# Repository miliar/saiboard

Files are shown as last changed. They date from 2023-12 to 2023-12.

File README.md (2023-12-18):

# Saiboard
Saiboard is an open-source Go board that combines tradition with technology.

Experience the thrill of Go on a real board, enhanced by AI guidance and analysis tools.

Play against AI, review your games with AI assistance, and elevate your Go skills to new heights.

https://github.com/miliar/saiboard/assets/35922697/eb32aec5-f142-464d-a071-56e9dbfe0f72

Features:

- Wooden Go [board](https://github.com/miliar/saiboard/tree/main/board) for authentic gameplay
- Sensory [electronics](https://github.com/miliar/saiboard/tree/main/electronics) for accurate move detection and LED feedback
- Heavy, magnetic Go [stones](https://github.com/miliar/saiboard/tree/main/stones) for a stable and engaging experience
- [Software](https://github.com/miliar/saiboard/tree/main/software ) with integrated AI system KataGo for expert insights and game recommendations
- User-friendly [web app](https://github.com/miliar/saiboard/tree/main/software/flutter/saiboard) for effortless control and interaction

## App
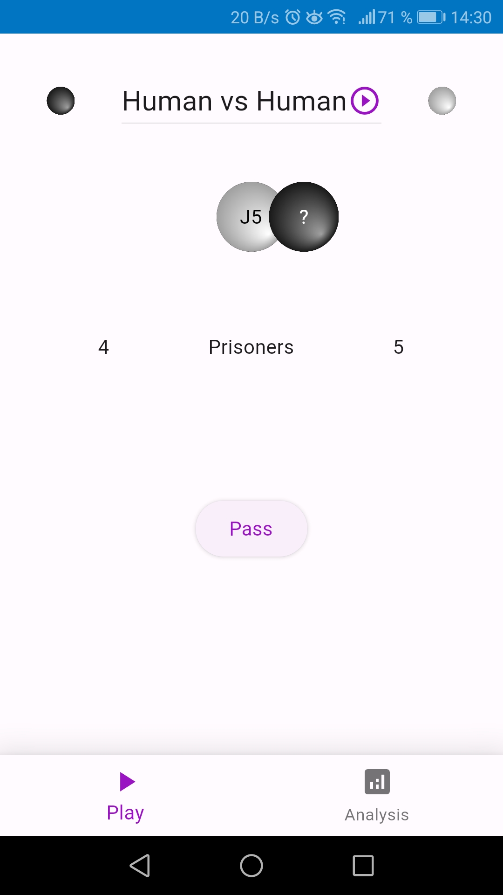
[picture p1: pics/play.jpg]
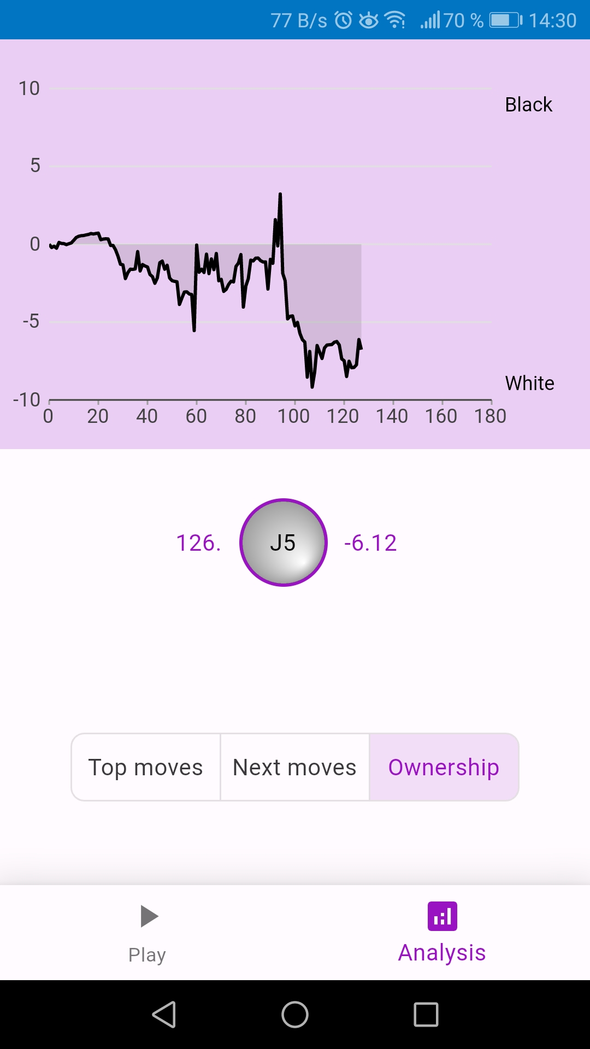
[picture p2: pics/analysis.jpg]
  

## Board
### Next moves
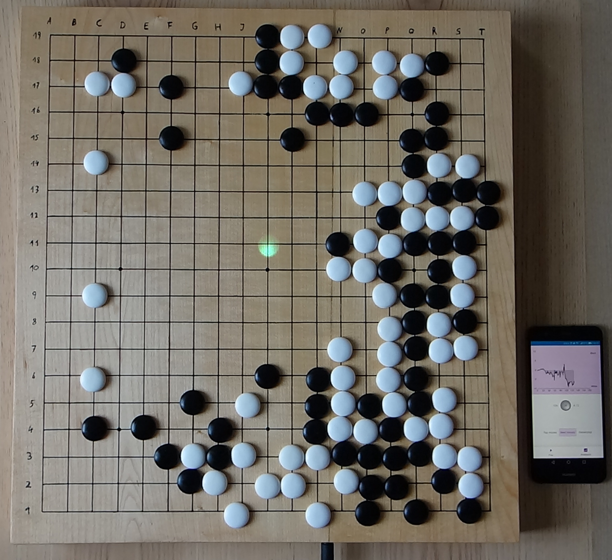
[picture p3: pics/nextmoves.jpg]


### Top moves
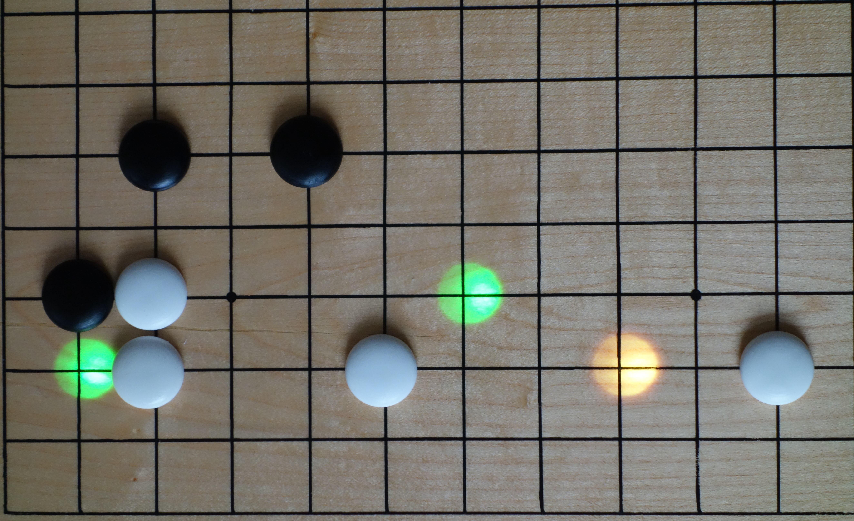
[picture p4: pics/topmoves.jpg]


### Ownership
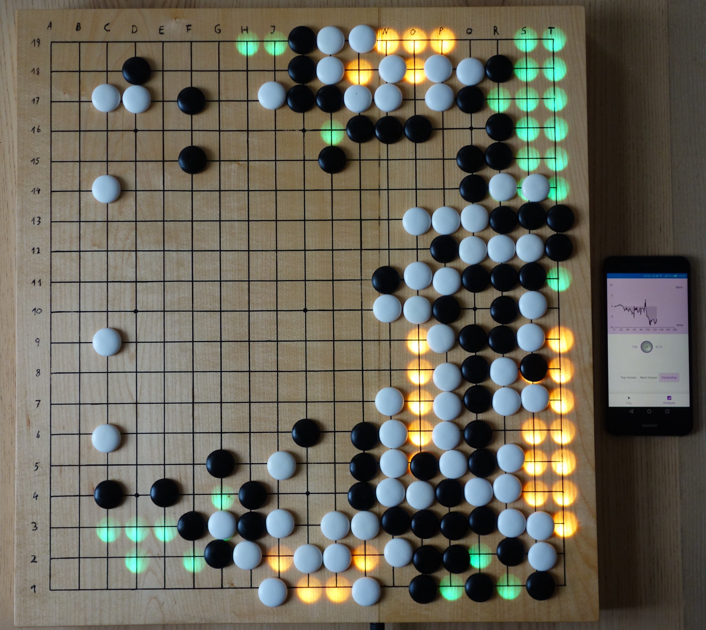
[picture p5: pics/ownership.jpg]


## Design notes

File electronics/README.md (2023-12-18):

# Electronics
The electronics consists of one touch plate, an array of 19x19 hall sensors (for detecting magnets) and LEDs. \
The touch plate is used to detect when a move is finished, so that sliding the stone in position is possible. \
It is controlled by an ESP32S3 microcontroller.\
To make the manufacturing process easier, the board is divided into several smaller PCBs. \
There is a power connection for a raspberry pi.

## How to build
### PCBs

- [Order](https://jlcpcb.com/) PCB/ Stencil
- [Solderpaste](https://www.mouser.de/ProductDetail/Chip-Quik/TS391AX50?qs=1mbolxNpo8c66lK8U%252Bbg8g%3D%3D)
- Solder led side first
- [Reflow oven](https://www.ninjakitchen.de/produkte/ninja-foodi-8-in-1-multifunktionsofen-sp101eu-zidSP101EU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): Bake 3 min, 0-90s: 125° C, 90-180s: 230° C, then open door
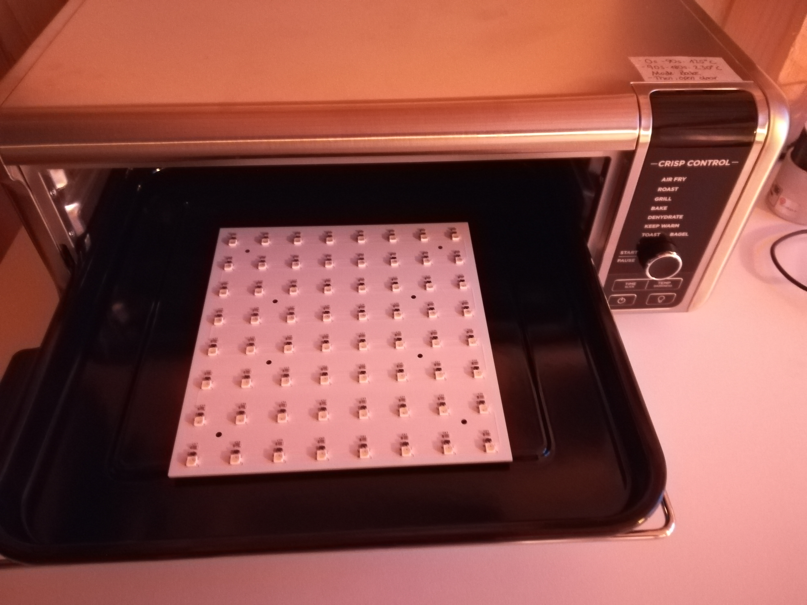
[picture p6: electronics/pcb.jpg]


- Print [plastic parts](/electronics/3d_prints/)
- Place pcb mask on first side, apply paste to the second side. Then remove pcb mask and bake pcb while placed on e.g. nuts

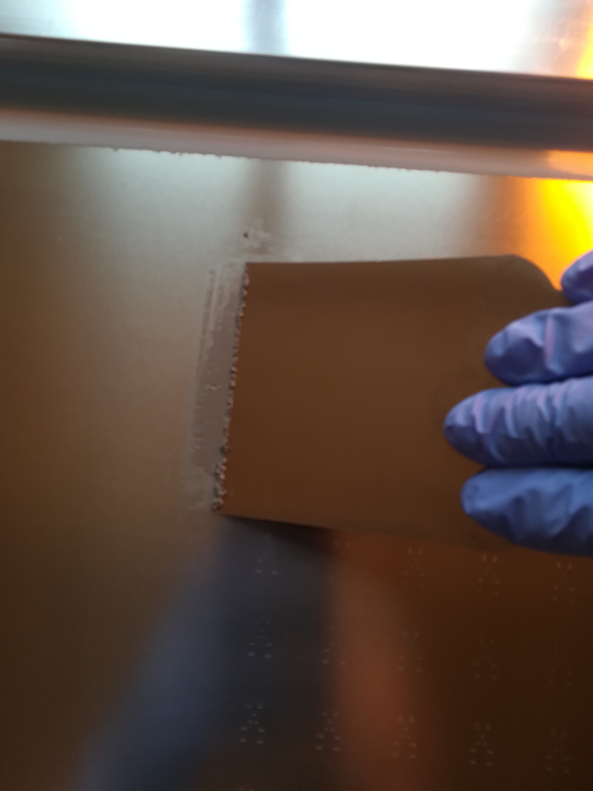
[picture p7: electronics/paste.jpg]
  

### Touch plate
Put copper foil on printed pcb-masks, remove foil from holes. Eletrical and physical connect all pcb masks. Glue non copper side to pcb first side with double sided tape. Solder connection to copper side and connect to touch pin of microcontroller.

### Mounting
- Press [esp32s3](https://docs.espressif.com/projects/esp-idf/en/latest/esp32s3/hw-reference/esp32s3/user-guide-devkitc-1.html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) in socket
- Use [screws](https://www.amazon.de/gp/product/B00XPJG1OC/ref=ppx_yo_dt_b_asin_title_o05_s00?ie=UTF8&psc=1) out of **stainless steel**.
- Enlarge mount holes of raspberry pi 4 to 3mm and fix it with the plastic mount. Connect power pins to board.
- Connect board power out to [adapter](https://www.amazon.de/Delock-Terminalblock-2pin-5mm-65421/dp/B009PH1J5Y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). Glue adapter into hole on the side of the board.
- Use a 5V/ 10A, 50W [power supply](https://www.amazon.de/LEICKE-Netzteil-Adapter-WS2812B-LED8806/dp/B07YVBHH6K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)

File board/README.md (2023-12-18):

# Board
The board has a top made of plywood with holes for the LED lights. \
A layer of veener is put over the holes to make a smooth surface. \
Resin is poured into the holes to protect the lights and make the board more sturdy.

## How to build
- Cut [pieces](/board/cnc_files/) out of plywood.
  - Thickness Sides: 10 mm Bottom: 5 mm Top: 6,5 mm
- [Glue](https://www.amazon.de/Titebond-Classic-Holzleim-118-506/dp/B0044UKJ62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) and clamp over night
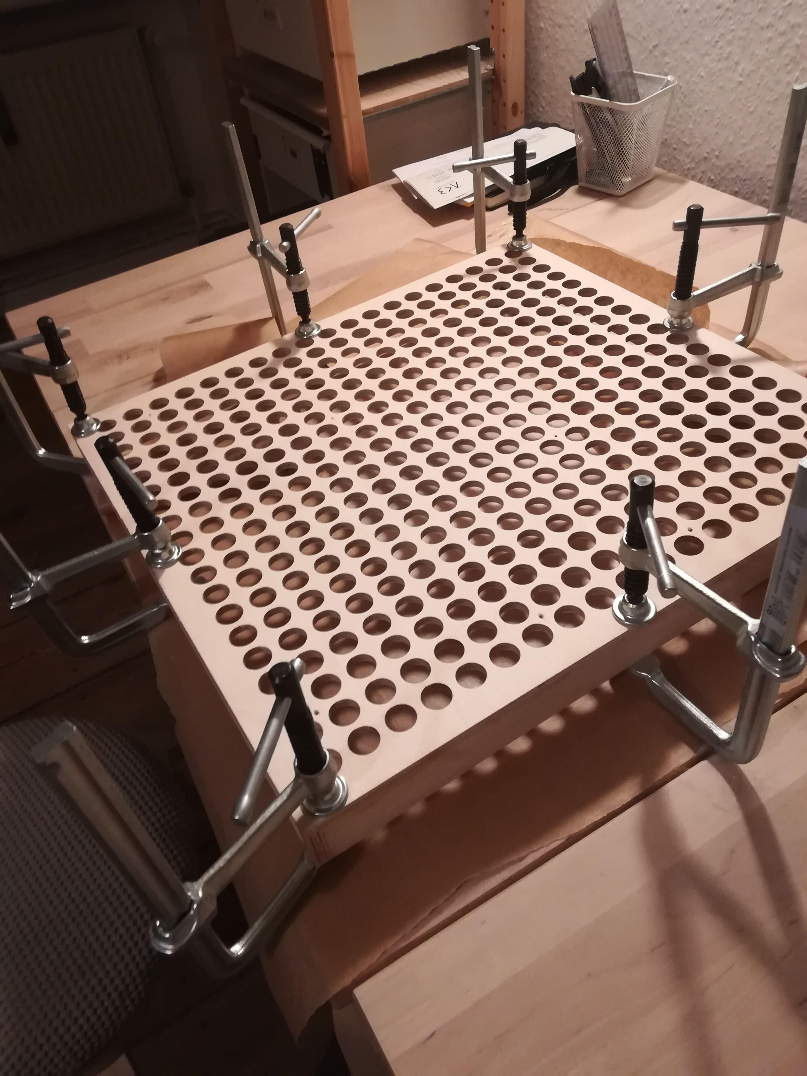
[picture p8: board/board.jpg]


- Sanding
- Cut pieces out of 0,6 mm thick veener, a bit larger area than top piece of board
- Put glue to the top of the board and to the veener, let it dry, then iron on veener.
- Cut or sand veener to size
- (Oil finish)
- Fill inside with enough resin to cover holes
- 4 layers of [poly](https://www.amazon.de/Minwax-polycryl-40910-wipe-%C3%96l-basierende-1-pint/dp/B01MU1VFWV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)
- Apply the grid. This [pen](https://www.amazon.de/rOtring-isograph-Tuschef%C3%BCller-0-8/dp/B000USK8KY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) works great. You can assemble the two 3d print files with a spring for a penholder similiar to [this instruction](https://www.instructables.com/Spring-loaded-CNC-Penholder-for-Rapidograph-techni/) and [use the cnc to apply the lines](https://www.reddit.com/r/baduk/comments/13xi005/tachi_mori_2023/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). Apply star points by hand.
- Finish with some layers of poly and sanding

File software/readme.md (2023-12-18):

# Software
The microcontroller chip on the board creates a local Wi-Fi network, to which you will need to connect your device. Once connected, you can access the Saiboard web interface by going to the local address 192.168.4.5:8000 .

The backend and frontend of Saiboard are hosted on the local Raspberry Pi. This setup keeps everything bundled into the board.

If you want to use a more powerful machine for a stronger and faster AI, you can install the backend on a different device.

## Architecture

The core of Saiboard's architecture is built around three main components:

- [esp32s3](https://github.com/miliar/saiboard/tree/main/software/esp32s3): This microcontroller chip handles the board's physical controls, communicates with the backend server, and creates the local Wi-Fi network.

- [backend](https://github.com/miliar/saiboard/tree/main/software/backend): This server software runs on the Raspberry Pi and provides the AI functionality, game logic, and interface capabilities.

- [saiboard](https://github.com/miliar/saiboard/tree/main/software/flutter/saiboard): This is the user interface (UI) part of Saiboard, which runs in your web browser and displays the game information and AI insights and also allows you to control the board directly.

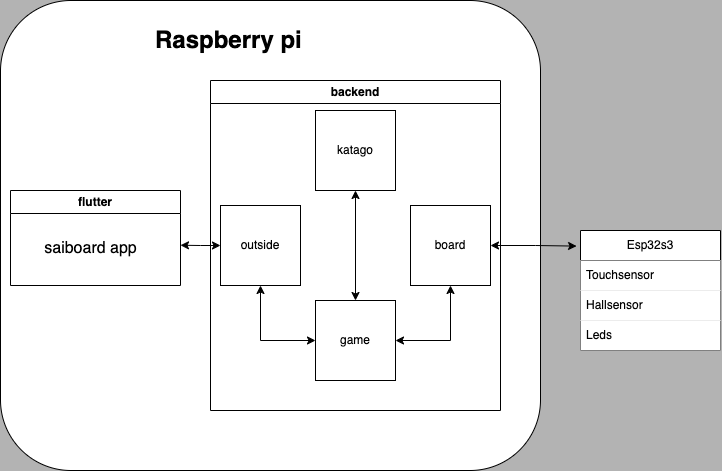
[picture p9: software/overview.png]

## Set up rasberry pi 4
- Install raspos 64 bit lite with ssh https://www.tomshardware.com/reviews/raspberry-pi-headless-setup-how-to,6028.html
- Install docker https://docs.docker.com/engine/install/debian/
- Add network in /etc/wpa_supplicant/wpa_supplicant.conf
- Prepend domain-name-servers 8.8.8.8, 8.8.4.4; >> /etc/dhcp/dhclient.conf , then sudo dhclient
- Set static ip for rasberry pi to 192.168.4.5(flutter needs static real ip for websocket) https://www.tomshardware.com/how-to/static-ip-raspberry-pi
- Add start up to /etc/rc.local:
```
    # docker backend
    sudo docker compose -f /home/rashid/backend/docker-compose.yml  up -d
    # flutter
    (cd /home/rashid/flutter  && sudo python -m http.server 8000) &
```

## Deploy to rasberry pi 4
### Deploy flutter
- `cd software/flutter/saiboard`
- `flutter clean`
- `flutter build web --web-renderer canvaskit --release`  https://docs.flutter.dev/deployment/web
- change wifi to saiboard
- `scp -r build/web/* rashid@saiboardrasp.local:/home/rashid/flutter` https://www.simplified.guide/ssh/copy-file
- delete browser cache for app

### Deploy backend
- `scp -r ../../backend/* rashid@saiboardrasp.local:/home/rashid/backend`
- `ssh saiboardrasp.local`
- `rm backend/katago/Dockerfile & mv backend/katago/Dockerfile_rasp backend/katago/Dockerfile`
- change network on rasberry pi to internet (`sudo nano /etc/wpa_supplicant/wpa_supplicant.conf`)
- reboot, connect via wifi internet,`ssh saiboardrasp.local` 
- `cd backend`
- `docker compose down`
- `docker compose build`
- In case of build errors like "Could not connect to ports.ubuntu.com:80", try:
    - `sudo dhclient`
    - `docker image prune -a`
- `docker compose up`
- change network back to saibord, reboot rasberry pi

## Deploy to esp32s3
- [linux/macos](https://docs.espressif.com/projects/esp-idf/en/latest/esp32s3/get-started/linux-macos-setup.html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)
- [via vscode extension](https://github.com/espressif/vscode-esp-idf-extension/blob/HEAD/docs/tutorial/basic_use.md)

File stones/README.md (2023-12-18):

# Stones
The stones are made from resin. \
They are filled with a small magnet that is enclosed in a hexagonal nut. This design serves two purposes: it helps to shield the magnetic field from interfering with others, and it adds weight to the stone for a better gaming experience. \
Each stone weighs approximately 3 grams. 

## How to make the silicone mold
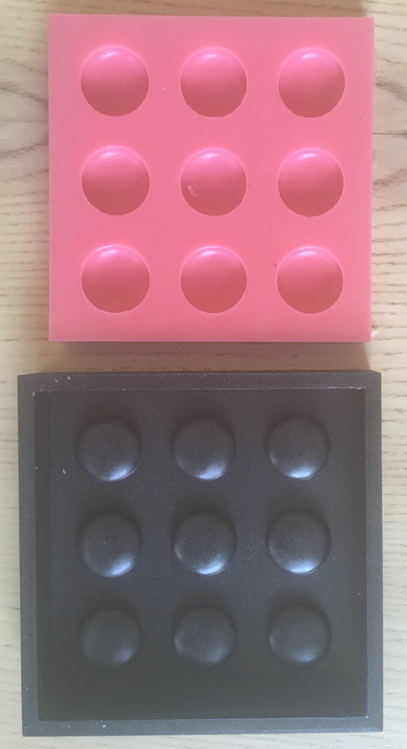
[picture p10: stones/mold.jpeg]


- 3d print the positive mold
- Sand it
- Use [Primer/Filler](https://www.amazon.de/edding-Permanent-Spray-Kunststoffgrundierung-Kunststoff-Oberfl%C3%A4chen/dp/B00CSLMC0U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) for smooth surface
- Fill with 130 g [silicone](https://www.amazon.de/Wagnersil-Premium-Silikon-Kautschuk-Dubliersilikon/dp/B01703HDWW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)

## How to make stones
- Mix [resin](https://www.amazon.de/Epoxidharz-Qualit%C3%A4t-geruchsarm-Laminier-Schutzhandschuhe/dp/B07D3SB9M9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) with 5% [color](https://www.amazon.de/100g-Farbpaste-schwarz-RAL-9005/dp/B00BIZDTEA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)
- Fill silicone mold with 0,3 ml
- Let it cure
- Push or hammer in 7x4 mm N35 neodym magnets in hexagon nut **zinc plated**( important because of magnetic properties) steel DIN 439 BM 8x1
- Place magnets into mold, **opposite** magnet direction for **each color**
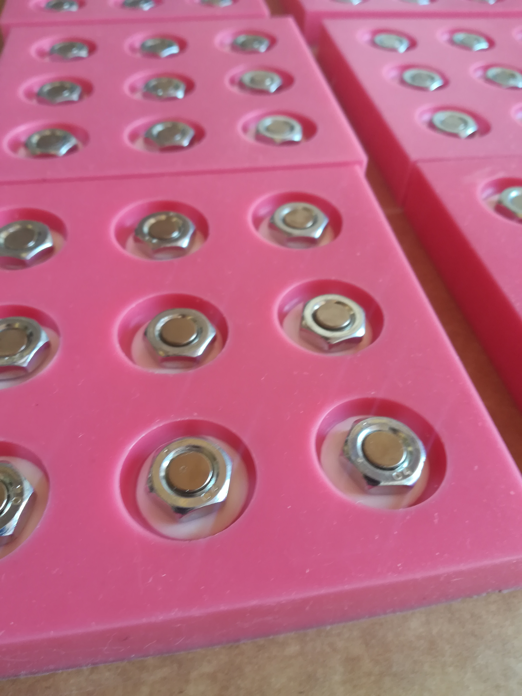
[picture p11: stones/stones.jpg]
  
- Fill up with 1,3 ml resin
- Remove bubbles with torch
- After curing, remove sharp edges by wet sanding of flat bottom and edge. For this, 3d print the stone holder and add one of the magnets to the hole.
- Rinse black stones with isopropanol and polish with a bit oil

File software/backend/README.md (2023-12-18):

# Overview
Backend runs 4 containers.
- [board](https://github.com/miliar/saiboard/tree/main/software/backend/board) interfaces with the physical board.
   

- [katago](https://github.com/miliar/saiboard/tree/main/software/backend/katago) is running the [katago analysis engine](https://github.com/lightvector/KataGo/blob/master/docs/Analysis_Engine.md) inside a docker container. There a 2 Dockerfiles for different host machine architectures
  

- [game](https://github.com/miliar/saiboard/tree/main/software/backend/game) contains all game logic.
   

- [outside](https://github.com/miliar/saiboard/tree/main/software/backend/board) interfaces with the UI.

It is deployed to a raspberry pi, but could also run from a more powerful server.
### Katago benchmark on raspberry pi 4
benchmark_rp4

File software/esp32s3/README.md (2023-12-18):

# Overview
The code creates a WiFi network with the name "saiboard" and the password "saiboard". \
It then runs a server that accepts TCP connections. \
The server responds to requests to turn the LED on or off, and it also sends sensor data back to the client. \
For more details, please see the accompanying [notebook](https://github.com/miliar/saiboard/blob/main/software/esp32s3/test_basic_components.ipynb).

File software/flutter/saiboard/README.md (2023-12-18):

# Overview
This Flutter web app is hosted on a Raspberry Pi and allows you to play against AI or a human opponent locally.

benchmark_rp4  benchmark_rp4

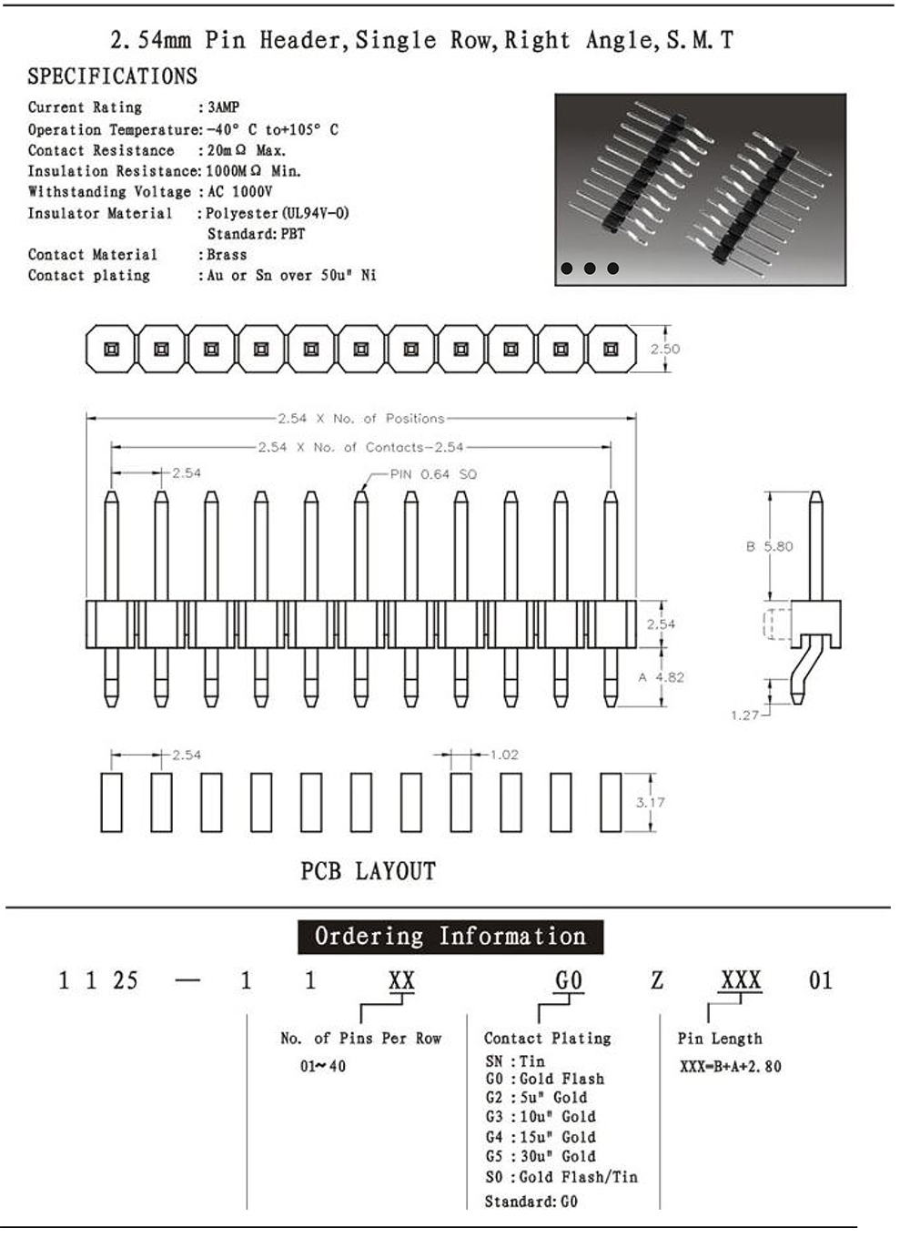
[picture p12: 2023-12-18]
electronics/datasheets/BOARD_CONNECTOR_MALE.jpg

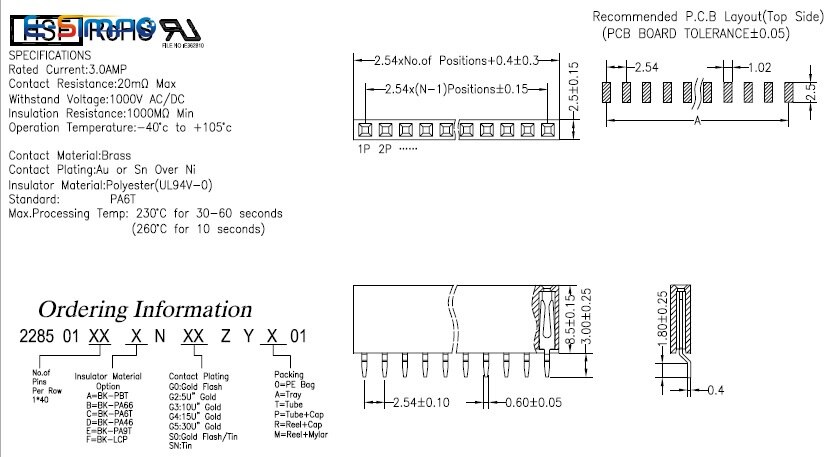
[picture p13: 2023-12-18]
electronics/datasheets/BOARD_CONNECTOR_FEMALE.jpg

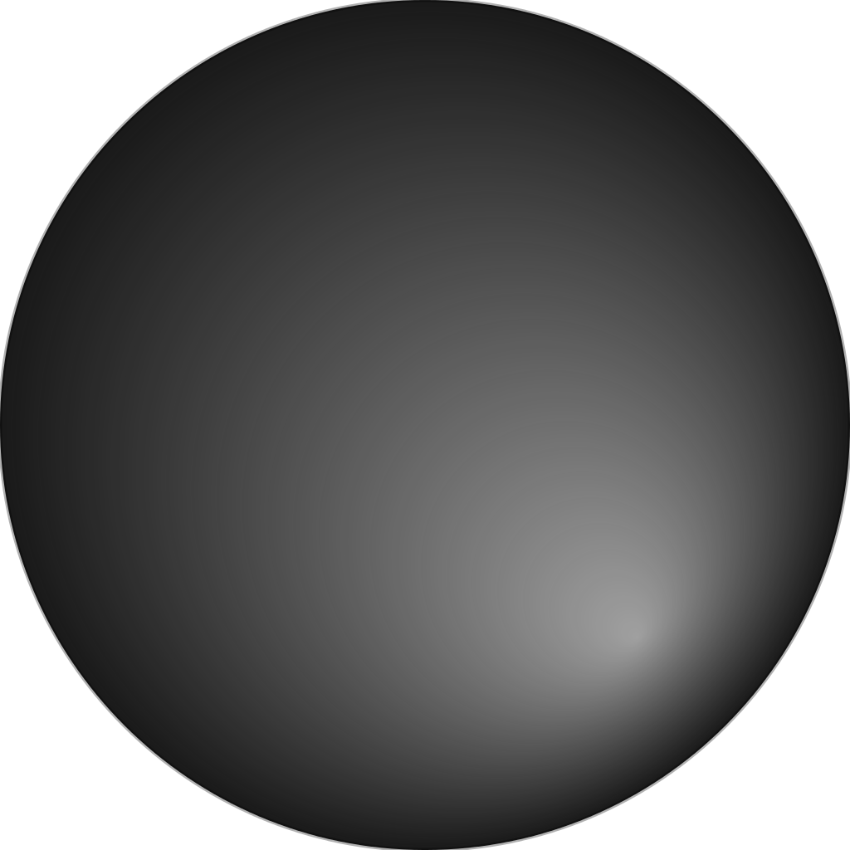
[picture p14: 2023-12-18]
software/flutter/saiboard/assets/images/black.png

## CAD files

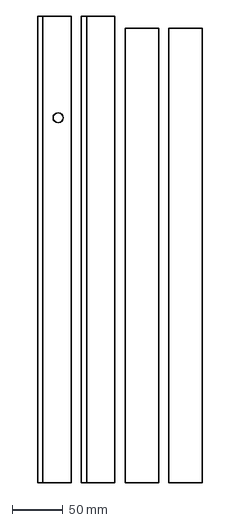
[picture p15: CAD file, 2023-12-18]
board/cnc_files/side.dxf
162.0 x 460.0 mm

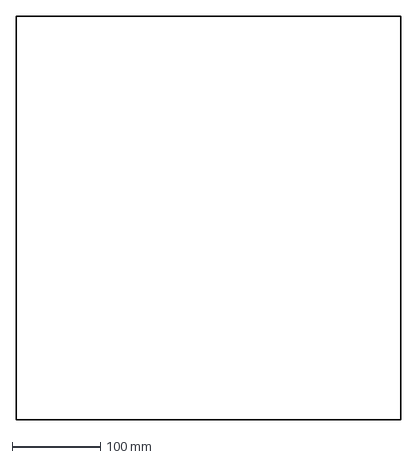
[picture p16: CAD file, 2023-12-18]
board/cnc_files/bottom.dxf
436.0 x 458.0 mm

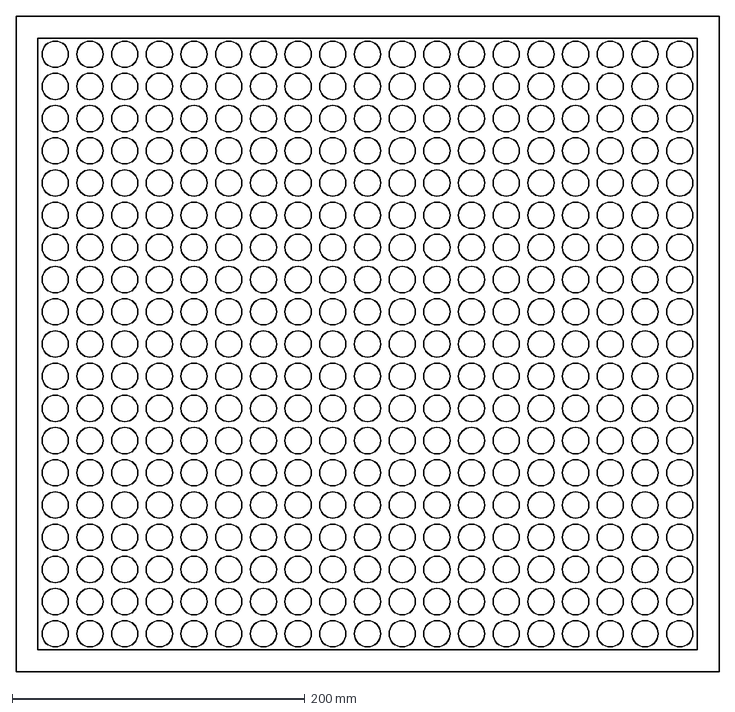
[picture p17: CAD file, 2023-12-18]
board/cnc_files/top.dxf
480.3 x 448.0 mm

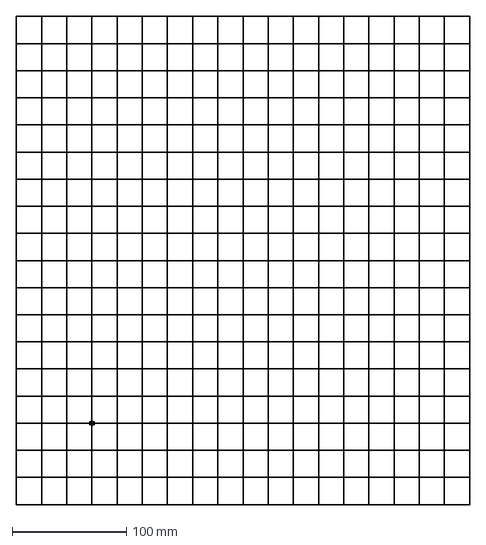
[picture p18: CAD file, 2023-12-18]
board/cnc_files/grid.dxf
396.0 x 426.6 mm

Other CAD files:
board/3d_prints/pen_part1.f3d
board/3d_prints/pen_part2.f3d
board/cnc_files/Top.f3d
board/cnc_files/bottom.f3d
board/cnc_files/grid.f3d
board/cnc_files/side.f3d
electronics/3d_prints/11x3_pcb_mask.f3d
electronics/3d_prints/3x8_pcb_mask.f3d
electronics/3d_prints/8x3_pcb_mask.f3d
electronics/3d_prints/raspberry_pi_mount.f3d
stones/3d_prints/go_stones_mold.f3d
stones/3d_prints/stone_holder.f3d

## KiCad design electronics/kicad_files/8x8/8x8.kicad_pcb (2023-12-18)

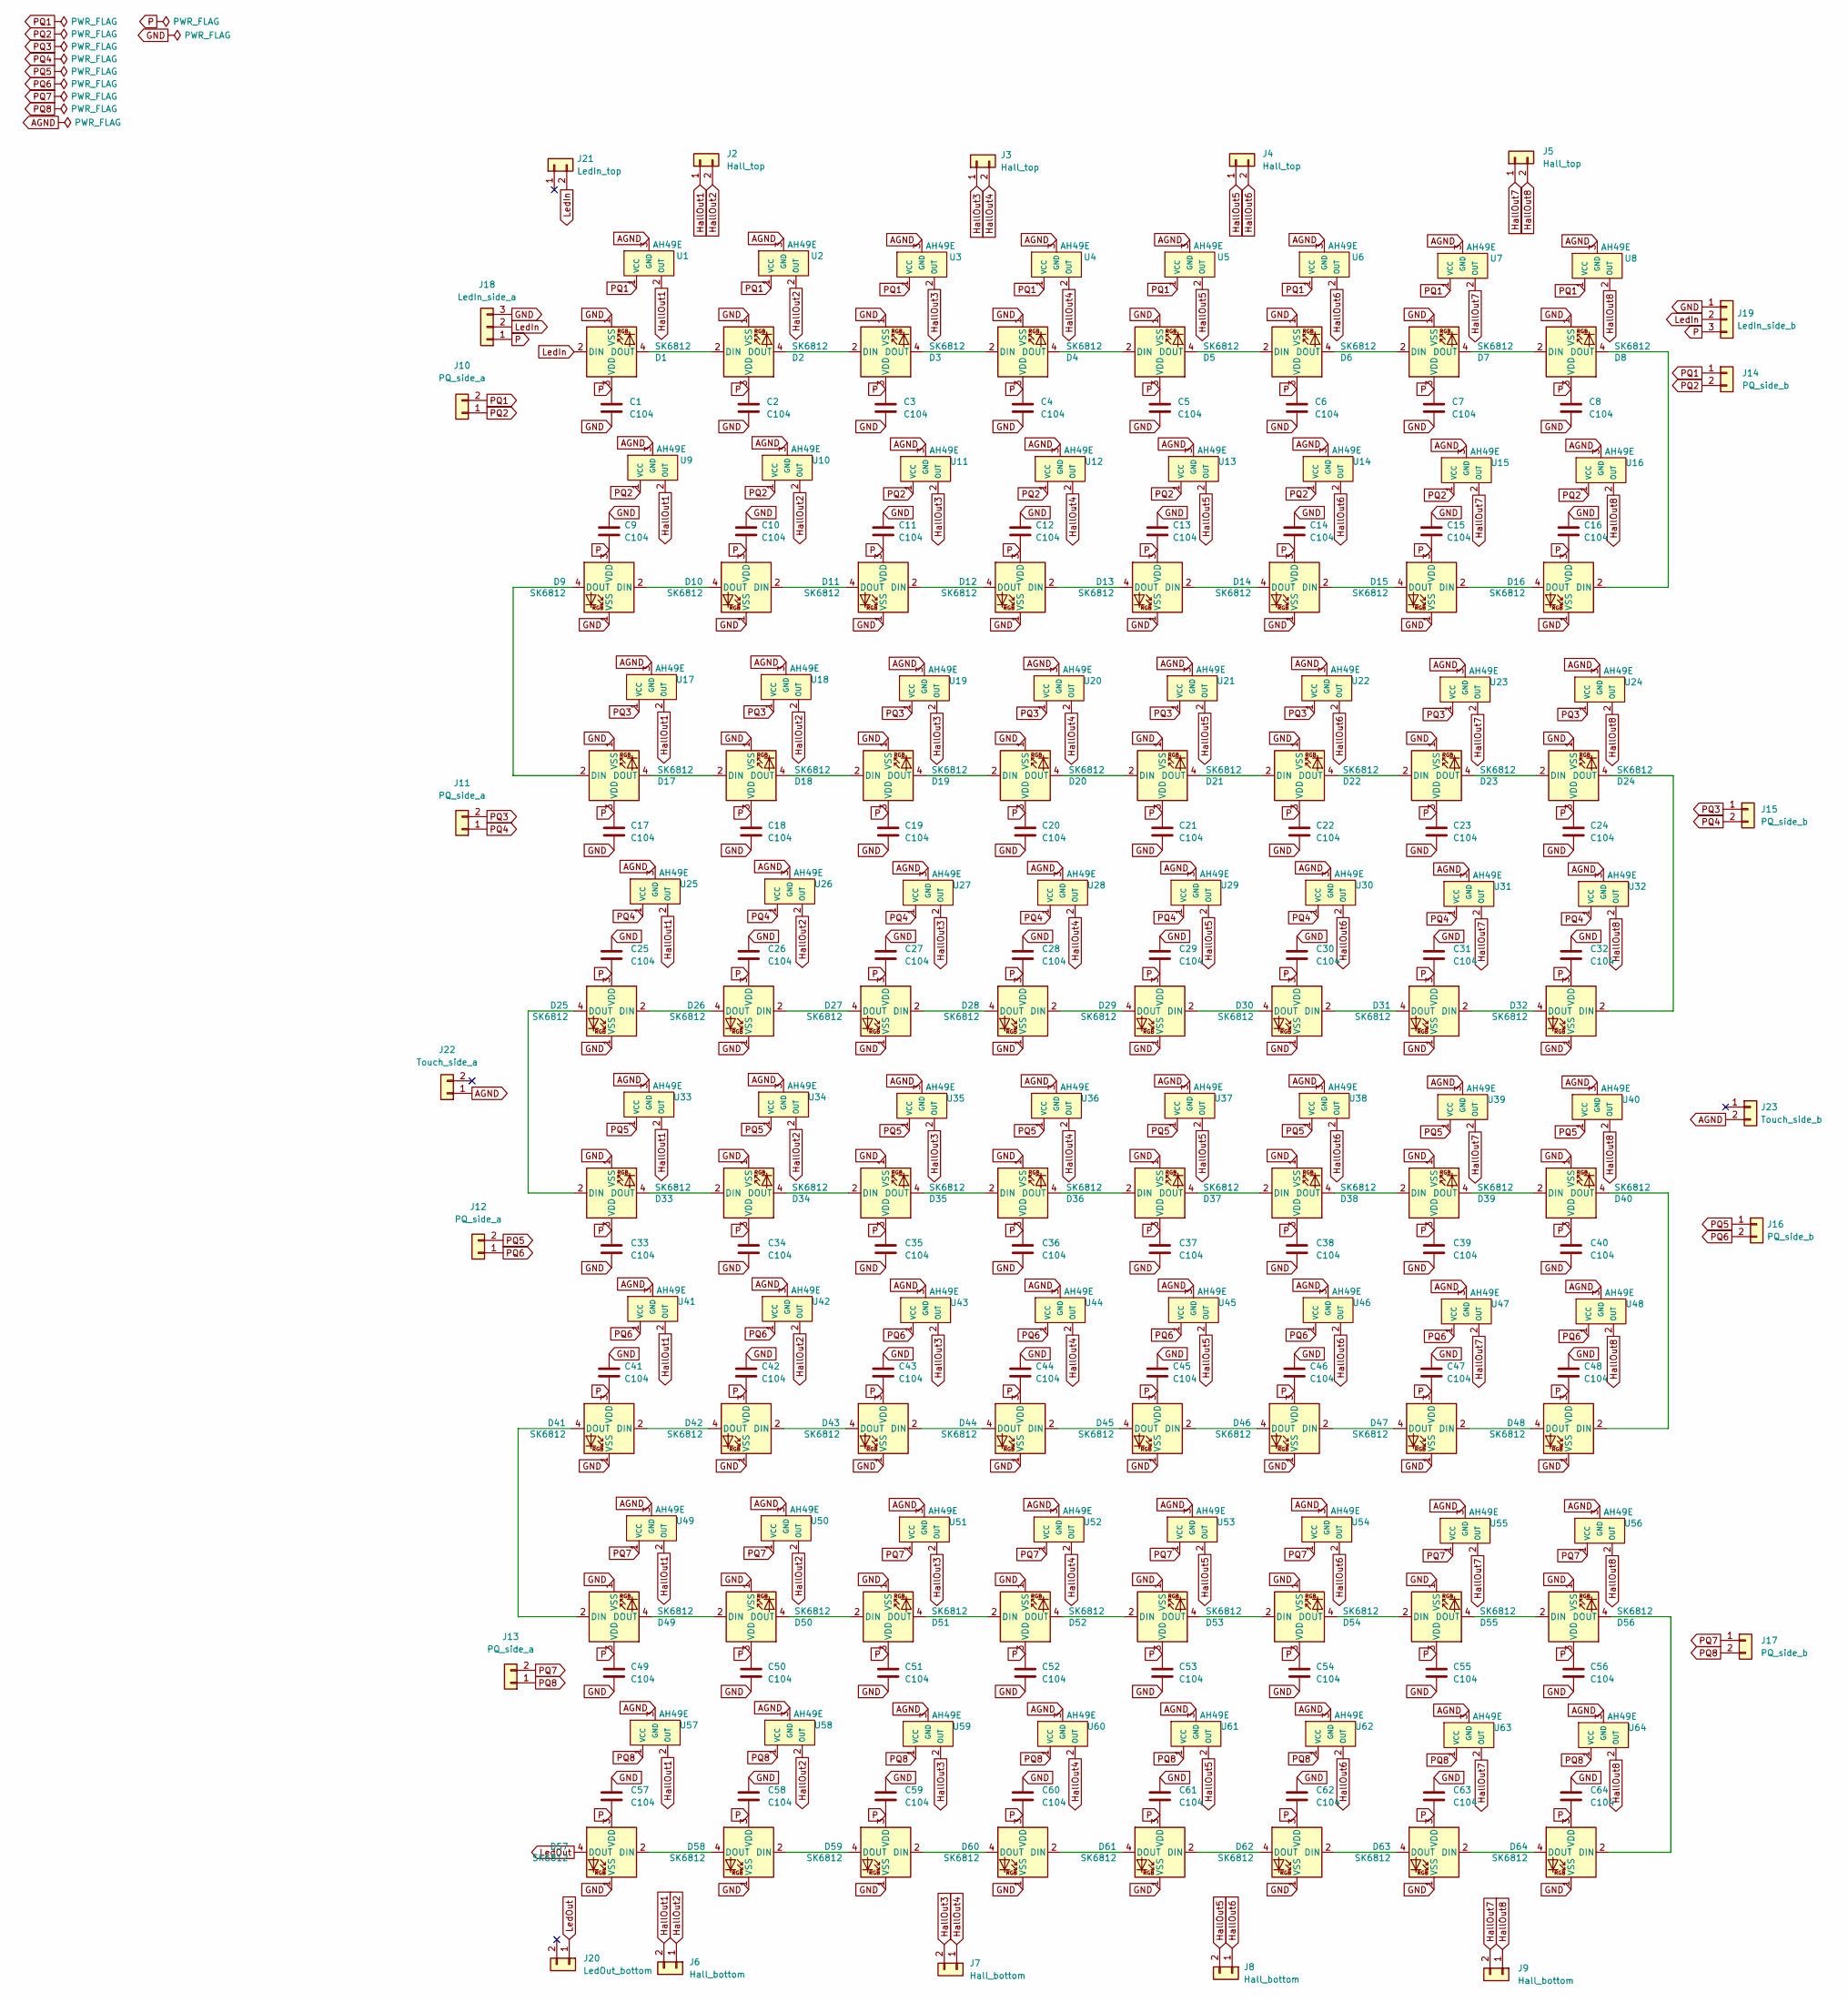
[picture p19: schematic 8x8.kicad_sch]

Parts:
C1, C2, C3, C4, C5, C6, C7, C8, C9, C10, C11, C12, C13, C14, C15, C16, C17, C18, C19, C20, C21, C22, C23, C24, C25, C26, C27, C28, C29, C30, C31, C32, C33, C34, C35, C36, C37, C38, C39, C40, C41, C42, C43, C44, C45, C46, C47, C48, C49, C50, C51, C52, C53, C54, C55, C56, C57, C58, C59, C60, C61, C62, C63, C64: C104; C_1206_3216Metric
D1, D2, D3, D4, D5, D6, D7, D8, D9, D10, D11, D12, D13, D14, D15, D16, D17, D18, D19, D20, D21, D22, D23, D24, D25, D26, D27, D28, D29, D30, D31, D32, D33, D34, D35, D36, D37, D38, D39, D40, D41, D42, D43, D44, D45, D46, D47, D48, D49, D50, D51, D52, D53, D54, D55, D56, D57, D58, D59, D60, D61, D62, D63, D64: SK6812; LED_SK6812_PLCC4_5.0x5.0mm_P3.2mm
J2, J3, J4, J5: Hall_top; PinHeader_1x02_P2.54mm_Horizontal_SMD
J6, J7, J8, J9: Hall_bottom; PinSocket_1x02_P2.54mm_Horizontal_SMD
J10, J11, J12, J13: PQ_side_a; PinSocket_1x02_P2.54mm_Horizontal_SMD
J14, J15, J16, J17: PQ_side_b; PinSocket_1x02_P2.54mm_Horizontal_SMD
J18: LedIn_side_a; PinSocket_1x03_P2.54mm_Horizontal_SMD
J19: LedIn_side_b; PinSocket_1x03_P2.54mm_Horizontal_SMD
J20: LedOut_bottom; PinSocket_1x02_P2.54mm_Horizontal_SMD
J21: LedIn_top; PinHeader_1x02_P2.54mm_Horizontal_SMD
J22: Touch_side_a; PinSocket_1x02_P2.54mm_Horizontal_SMD
J23: Touch_side_b; PinSocket_1x02_P2.54mm_Horizontal_SMD
U1, U2, U3, U4, U5, U6, U7, U8, U9, U10, U11, U12, U13, U14, U15, U16, U17, U18, U19, U20, U21, U22, U23, U24, U25, U26, U27, U28, U29, U30, U31, U32, U33, U34, U35, U36, U37, U38, U39, U40, U41, U42, U43, U44, U45, U46, U47, U48, U49, U50, U51, U52, U53, U54, U55, U56, U57, U58, U59, U60, U61, U62, U63, U64: AH49E; SOT-23

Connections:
AGND: J22.1, J23.2, U1.3 (GND), U2.3 (GND), U3.3 (GND), U4.3 (GND), U5.3 (GND), U6.3 (GND), U7.3 (GND), U8.3 (GND), U9.3 (GND), U10.3 (GND), U11.3 (GND), U12.3 (GND), U13.3 (GND), U14.3 (GND), U15.3 (GND), U16.3 (GND), U17.3 (GND), U18.3 (GND), U19.3 (GND), U20.3 (GND), U21.3 (GND), U22.3 (GND), U23.3 (GND), U24.3 (GND), U25.3 (GND), U26.3 (GND), U27.3 (GND), U28.3 (GND), U29.3 (GND), U30.3 (GND), U31.3 (GND), U32.3 (GND), U33.3 (GND), U34.3 (GND), U35.3 (GND), U36.3 (GND), U37.3 (GND), U38.3 (GND), U39.3 (GND), U40.3 (GND), U41.3 (GND), U42.3 (GND), U43.3 (GND), U44.3 (GND), U45.3 (GND), U46.3 (GND), U47.3 (GND), U48.3 (GND), U49.3 (GND), U50.3 (GND), U51.3 (GND), U52.3 (GND), U53.3 (GND), U54.3 (GND), U55.3 (GND), U56.3 (GND), U57.3 (GND), U58.3 (GND), U59.3 (GND), U60.3 (GND), U61.3 (GND), U62.3 (GND), U63.3 (GND), U64.3 (GND)
GND: C1.2, C2.2, C3.2, C4.2, C5.2, C6.2, C7.2, C8.2, C9.2, C10.2, C11.2, C12.2, C13.2, C14.2, C15.2, C16.2, C17.2, C18.2, C19.2, C20.2, C21.2, C22.2, C23.2, C24.2, C25.2, C26.2, C27.2, C28.2, C29.2, C30.2, C31.2, C32.2, C33.2, C34.2, C35.2, C36.2, C37.2, C38.2, C39.2, C40.2, C41.2, C42.2, C43.2, C44.2, C45.2, C46.2, C47.2, C48.2, C49.2, C50.2, C51.2, C52.2, C53.2, C54.2, C55.2, C56.2, C57.2, C58.2, C59.2, C60.2, C61.2, C62.2, C63.2, C64.2, D1.1 (VSS), D2.1 (VSS), D3.1 (VSS), D4.1 (VSS), D5.1 (VSS), D6.1 (VSS), D7.1 (VSS), D8.1 (VSS), D9.1 (VSS), D10.1 (VSS), D11.1 (VSS), D12.1 (VSS), D13.1 (VSS), D14.1 (VSS), D15.1 (VSS), D16.1 (VSS), D17.1 (VSS), D18.1 (VSS), D19.1 (VSS), D20.1 (VSS), D21.1 (VSS), D22.1 (VSS), D23.1 (VSS), D24.1 (VSS), D25.1 (VSS), D26.1 (VSS), D27.1 (VSS), D28.1 (VSS), D29.1 (VSS), D30.1 (VSS), D31.1 (VSS), D32.1 (VSS), D33.1 (VSS), D34.1 (VSS), D35.1 (VSS), D36.1 (VSS), D37.1 (VSS), D38.1 (VSS), D39.1 (VSS), D40.1 (VSS), D41.1 (VSS), D42.1 (VSS), D43.1 (VSS), D44.1 (VSS), D45.1 (VSS), D46.1 (VSS), D47.1 (VSS), D48.1 (VSS), D49.1 (VSS), D50.1 (VSS), D51.1 (VSS), D52.1 (VSS), D53.1 (VSS), D54.1 (VSS), D55.1 (VSS), D56.1 (VSS), D57.1 (VSS), D58.1 (VSS), D59.1 (VSS), D60.1 (VSS), D61.1 (VSS), D62.1 (VSS), D63.1 (VSS), D64.1 (VSS), J18.3, J19.1
HallOut1: J2.1, J6.2, U1.2 (OUT), U9.2 (OUT), U17.2 (OUT), U25.2 (OUT), U33.2 (OUT), U41.2 (OUT), U49.2 (OUT), U57.2 (OUT)
HallOut2: J2.2, J6.1, U2.2 (OUT), U10.2 (OUT), U18.2 (OUT), U26.2 (OUT), U34.2 (OUT), U42.2 (OUT), U50.2 (OUT), U58.2 (OUT)
HallOut3: J3.1, J7.2, U3.2 (OUT), U11.2 (OUT), U19.2 (OUT), U27.2 (OUT), U35.2 (OUT), U43.2 (OUT), U51.2 (OUT), U59.2 (OUT)
HallOut4: J3.2, J7.1, U4.2 (OUT), U12.2 (OUT), U20.2 (OUT), U28.2 (OUT), U36.2 (OUT), U44.2 (OUT), U52.2 (OUT), U60.2 (OUT)
HallOut5: J4.1, J8.2, U5.2 (OUT), U13.2 (OUT), U21.2 (OUT), U29.2 (OUT), U37.2 (OUT), U45.2 (OUT), U53.2 (OUT), U61.2 (OUT)
HallOut6: J4.2, J8.1, U6.2 (OUT), U14.2 (OUT), U22.2 (OUT), U30.2 (OUT), U38.2 (OUT), U46.2 (OUT), U54.2 (OUT), U62.2 (OUT)
HallOut7: J5.1, J9.2, U7.2 (OUT), U15.2 (OUT), U23.2 (OUT), U31.2 (OUT), U39.2 (OUT), U47.2 (OUT), U55.2 (OUT), U63.2 (OUT)
HallOut8: J5.2, J9.1, U8.2 (OUT), U16.2 (OUT), U24.2 (OUT), U32.2 (OUT), U40.2 (OUT), U48.2 (OUT), U56.2 (OUT), U64.2 (OUT)
LedIn: D1.2 (DIN), J18.2, J19.2, J21.2
LedOut: D57.4 (DOUT), J20.1
unnamed: D1.4 (DOUT), D2.2 (DIN)
unnamed: D2.4 (DOUT), D3.2 (DIN)
unnamed: D3.4 (DOUT), D4.2 (DIN)
unnamed: D4.4 (DOUT), D5.2 (DIN)
unnamed: D5.4 (DOUT), D6.2 (DIN)
unnamed: D6.4 (DOUT), D7.2 (DIN)
unnamed: D7.4 (DOUT), D8.2 (DIN)
unnamed: D10.2 (DIN), D11.4 (DOUT)
unnamed: D9.2 (DIN), D10.4 (DOUT)
unnamed: D11.2 (DIN), D12.4 (DOUT)
unnamed: D12.2 (DIN), D13.4 (DOUT)
unnamed: D13.2 (DIN), D14.4 (DOUT)
unnamed: D14.2 (DIN), D15.4 (DOUT)
unnamed: D15.2 (DIN), D16.4 (DOUT)
unnamed: D8.4 (DOUT), D16.2 (DIN)
unnamed: D9.4 (DOUT), D17.2 (DIN)
unnamed: D17.4 (DOUT), D18.2 (DIN)
unnamed: D18.4 (DOUT), D19.2 (DIN)
unnamed: D19.4 (DOUT), D20.2 (DIN)
unnamed: D20.4 (DOUT), D21.2 (DIN)
unnamed: D21.4 (DOUT), D22.2 (DIN)
unnamed: D22.4 (DOUT), D23.2 (DIN)
unnamed: D23.4 (DOUT), D24.2 (DIN)
unnamed: D24.4 (DOUT), D32.2 (DIN)
unnamed: D25.2 (DIN), D26.4 (DOUT)
unnamed: D25.4 (DOUT), D33.2 (DIN)
unnamed: D26.2 (DIN), D27.4 (DOUT)
unnamed: D27.2 (DIN), D28.4 (DOUT)
unnamed: D28.2 (DIN), D29.4 (DOUT)
unnamed: D29.2 (DIN), D30.4 (DOUT)
unnamed: D30.2 (DIN), D31.4 (DOUT)
unnamed: D31.2 (DIN), D32.4 (DOUT)
unnamed: D33.4 (DOUT), D34.2 (DIN)
unnamed: D34.4 (DOUT), D35.2 (DIN)
unnamed: D35.4 (DOUT), D36.2 (DIN)
unnamed: D36.4 (DOUT), D37.2 (DIN)
unnamed: D37.4 (DOUT), D38.2 (DIN)
unnamed: D38.4 (DOUT), D39.2 (DIN)
unnamed: D39.4 (DOUT), D40.2 (DIN)
unnamed: D40.4 (DOUT), D48.2 (DIN)
unnamed: D41.2 (DIN), D42.4 (DOUT)
unnamed: D41.4 (DOUT), D49.2 (DIN)
unnamed: D42.2 (DIN), D43.4 (DOUT)
unnamed: D43.2 (DIN), D44.4 (DOUT)
unnamed: D44.2 (DIN), D45.4 (DOUT)
unnamed: D45.2 (DIN), D46.4 (DOUT)
unnamed: D46.2 (DIN), D47.4 (DOUT)
unnamed: D47.2 (DIN), D48.4 (DOUT)
unnamed: D49.4 (DOUT), D50.2 (DIN)
unnamed: D50.4 (DOUT), D51.2 (DIN)
unnamed: D51.4 (DOUT), D52.2 (DIN)
unnamed: D52.4 (DOUT), D53.2 (DIN)
unnamed: D53.4 (DOUT), D54.2 (DIN)
unnamed: D54.4 (DOUT), D55.2 (DIN)
unnamed: D55.4 (DOUT), D56.2 (DIN)
unnamed: D56.4 (DOUT), D64.2 (DIN)
unnamed: D57.2 (DIN), D58.4 (DOUT)
unnamed: D58.2 (DIN), D59.4 (DOUT)
unnamed: D59.2 (DIN), D60.4 (DOUT)
unnamed: D60.2 (DIN), D61.4 (DOUT)
unnamed: D61.2 (DIN), D62.4 (DOUT)
unnamed: D62.2 (DIN), D63.4 (DOUT)
unnamed: D63.2 (DIN), D64.4 (DOUT)
P: C1.1, C2.1, C3.1, C4.1, C5.1, C6.1, C7.1, C8.1, C9.1, C10.1, C11.1, C12.1, C13.1, C14.1, C15.1, C16.1, C17.1, C18.1, C19.1, C20.1, C21.1, C22.1, C23.1, C24.1, C25.1, C26.1, C27.1, C28.1, C29.1, C30.1, C31.1, C32.1, C33.1, C34.1, C35.1, C36.1, C37.1, C38.1, C39.1, C40.1, C41.1, C42.1, C43.1, C44.1, C45.1, C46.1, C47.1, C48.1, C49.1, C50.1, C51.1, C52.1, C53.1, C54.1, C55.1, C56.1, C57.1, C58.1, C59.1, C60.1, C61.1, C62.1, C63.1, C64.1, D1.3 (VDD), D2.3 (VDD), D3.3 (VDD), D4.3 (VDD), D5.3 (VDD), D6.3 (VDD), D7.3 (VDD), D8.3 (VDD), D9.3 (VDD), D10.3 (VDD), D11.3 (VDD), D12.3 (VDD), D13.3 (VDD), D14.3 (VDD), D15.3 (VDD), D16.3 (VDD), D17.3 (VDD), D18.3 (VDD), D19.3 (VDD), D20.3 (VDD), D21.3 (VDD), D22.3 (VDD), D23.3 (VDD), D24.3 (VDD), D25.3 (VDD), D26.3 (VDD), D27.3 (VDD), D28.3 (VDD), D29.3 (VDD), D30.3 (VDD), D31.3 (VDD), D32.3 (VDD), D33.3 (VDD), D34.3 (VDD), D35.3 (VDD), D36.3 (VDD), D37.3 (VDD), D38.3 (VDD), D39.3 (VDD), D40.3 (VDD), D41.3 (VDD), D42.3 (VDD), D43.3 (VDD), D44.3 (VDD), D45.3 (VDD), D46.3 (VDD), D47.3 (VDD), D48.3 (VDD), D49.3 (VDD), D50.3 (VDD), D51.3 (VDD), D52.3 (VDD), D53.3 (VDD), D54.3 (VDD), D55.3 (VDD), D56.3 (VDD), D57.3 (VDD), D58.3 (VDD), D59.3 (VDD), D60.3 (VDD), D61.3 (VDD), D62.3 (VDD), D63.3 (VDD), D64.3 (VDD), J18.1, J19.3
PQ1: J10.2, J14.1, U1.1 (VCC), U2.1 (VCC), U3.1 (VCC), U4.1 (VCC), U5.1 (VCC), U6.1 (VCC), U7.1 (VCC), U8.1 (VCC)
PQ2: J10.1, J14.2, U9.1 (VCC), U10.1 (VCC), U11.1 (VCC), U12.1 (VCC), U13.1 (VCC), U14.1 (VCC), U15.1 (VCC), U16.1 (VCC)
PQ3: J11.2, J15.1, U17.1 (VCC), U18.1 (VCC), U19.1 (VCC), U20.1 (VCC), U21.1 (VCC), U22.1 (VCC), U23.1 (VCC), U24.1 (VCC)
PQ4: J11.1, J15.2, U25.1 (VCC), U26.1 (VCC), U27.1 (VCC), U28.1 (VCC), U29.1 (VCC), U30.1 (VCC), U31.1 (VCC), U32.1 (VCC)
PQ5: J12.2, J16.1, U33.1 (VCC), U34.1 (VCC), U35.1 (VCC), U36.1 (VCC), U37.1 (VCC), U38.1 (VCC), U39.1 (VCC), U40.1 (VCC)
PQ6: J12.1, J16.2, U41.1 (VCC), U42.1 (VCC), U43.1 (VCC), U44.1 (VCC), U45.1 (VCC), U46.1 (VCC), U47.1 (VCC), U48.1 (VCC)
PQ7: J13.2, J17.1, U49.1 (VCC), U50.1 (VCC), U51.1 (VCC), U52.1 (VCC), U53.1 (VCC), U54.1 (VCC), U55.1 (VCC), U56.1 (VCC)
PQ8: J13.1, J17.2, U57.1 (VCC), U58.1 (VCC), U59.1 (VCC), U60.1 (VCC), U61.1 (VCC), U62.1 (VCC), U63.1 (VCC), U64.1 (VCC)

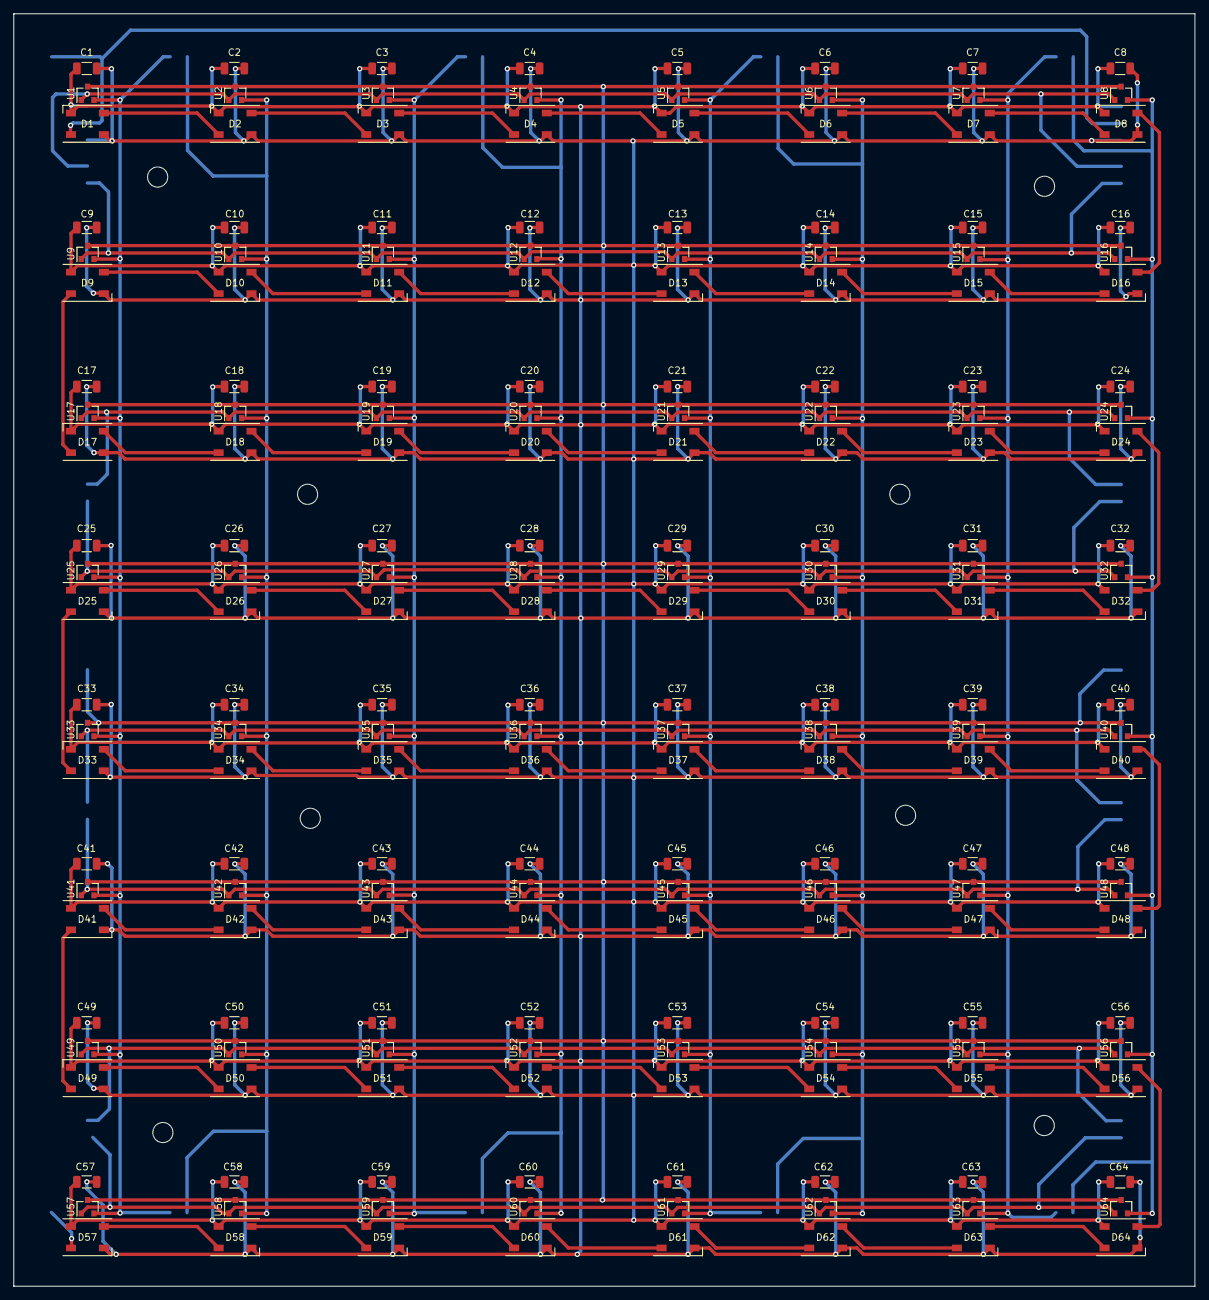
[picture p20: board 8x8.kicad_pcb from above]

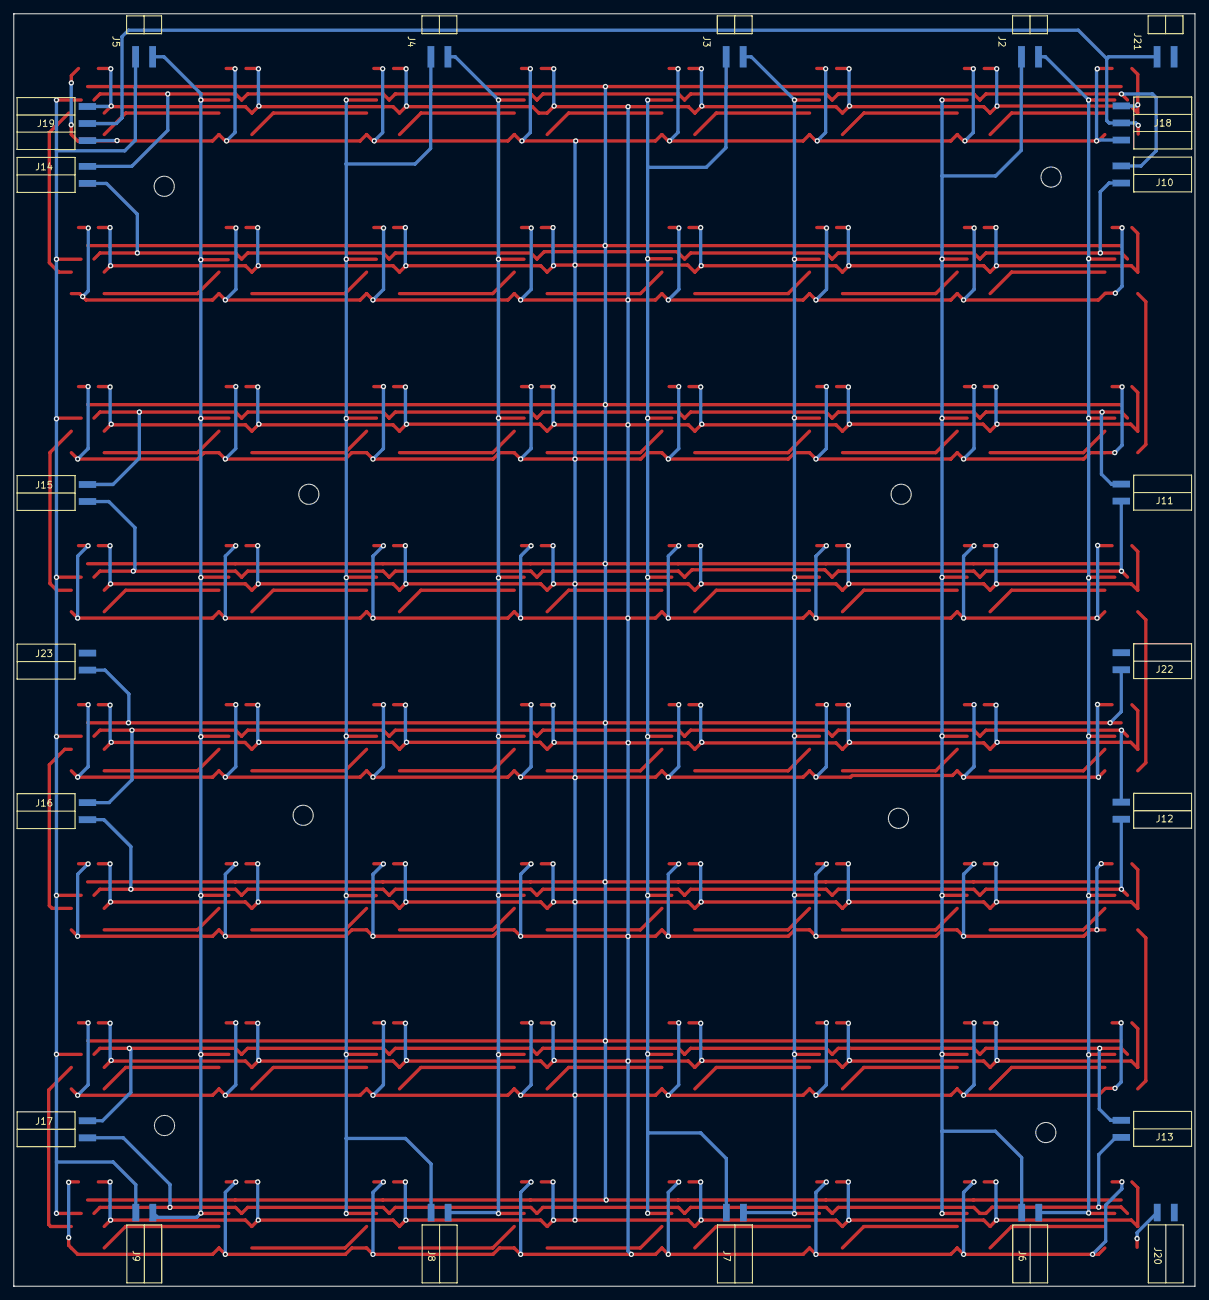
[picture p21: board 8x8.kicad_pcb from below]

Board: 2 copper layers, 176.0 x 189.6 mm, 222 parts (22 on the bottom side), 84 nets.

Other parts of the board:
m1, m1#2, m1#3, m1#4, m1#5, m1#6, m1#7, m2: MountingHole_3mm

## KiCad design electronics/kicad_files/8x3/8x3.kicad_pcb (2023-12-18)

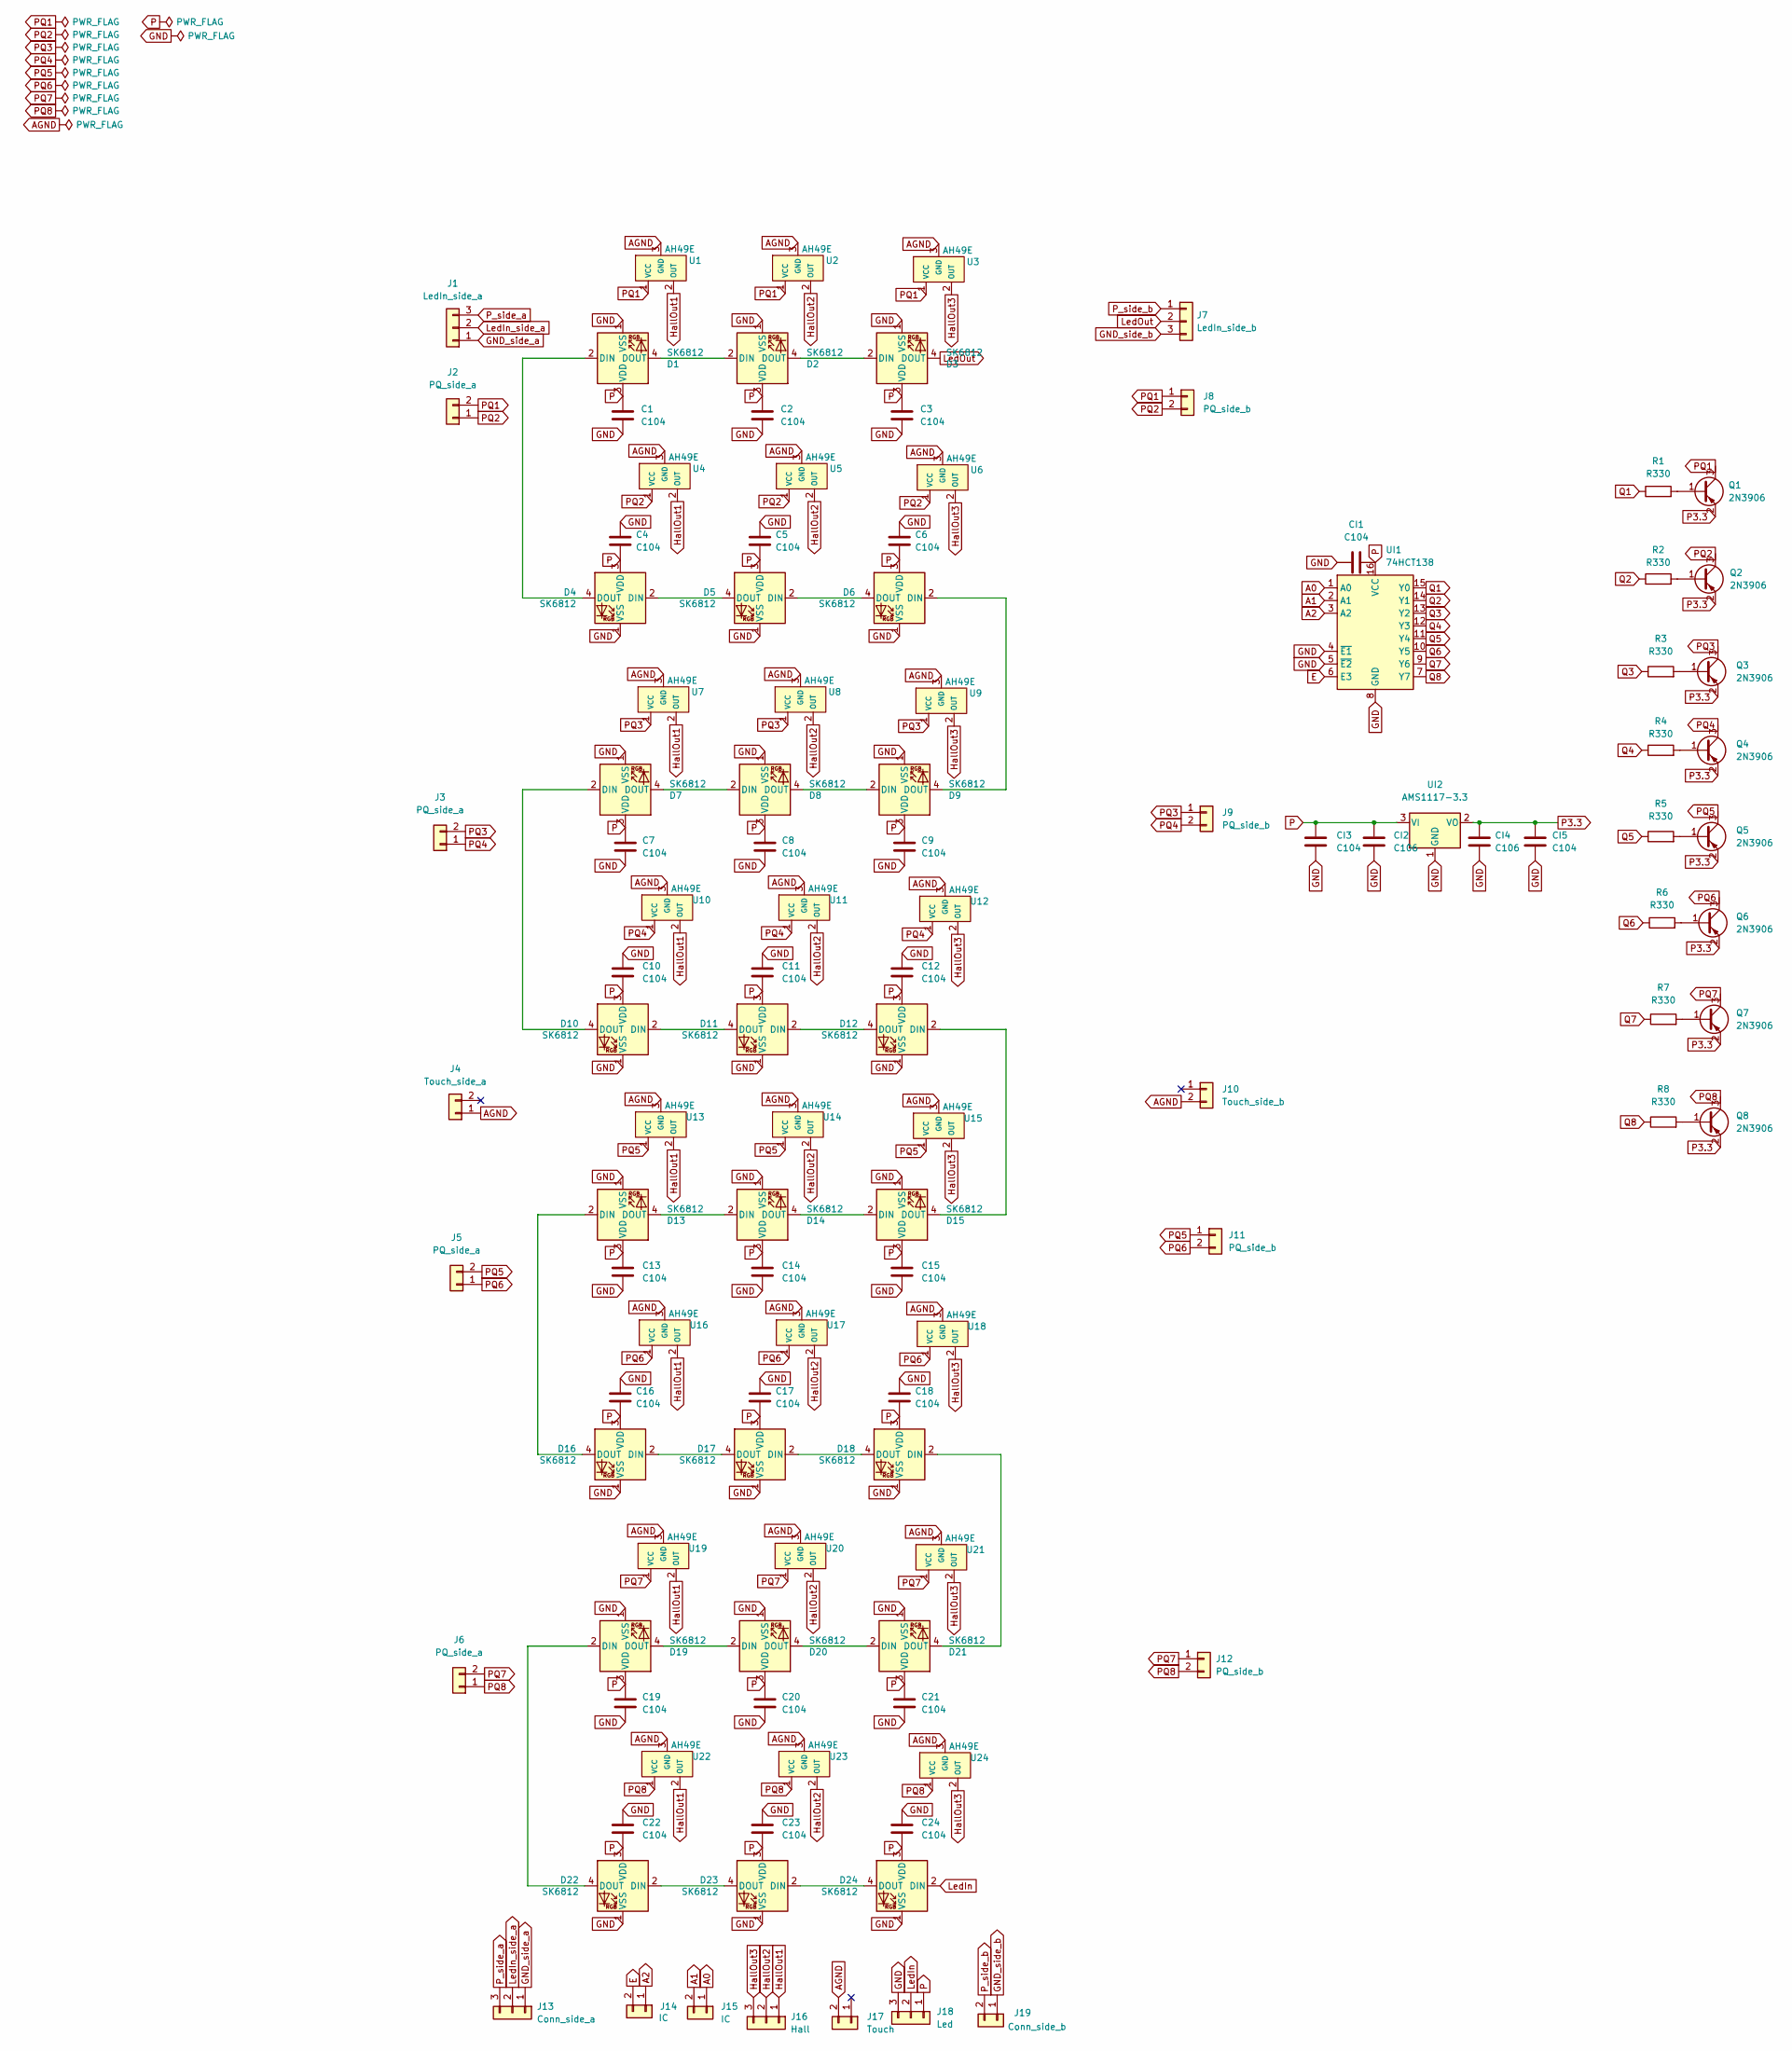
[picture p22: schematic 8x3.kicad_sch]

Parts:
C1, C2, C3, C4, C5, C6, C7, C8, C9, C10, C11, C12, C13, C14, C15, C16, C17, C18, C19, C20, C21, C22, C23, C24: C104; C_1206_3216Metric
CI1, CI3, CI5: C104; C_1206_3216Metric
CI2, CI4: C106; C_1206_3216Metric
D1, D2, D3, D4, D5, D6, D7, D8, D9, D10, D11, D12, D13, D14, D15, D16, D17, D18, D19, D20, D21, D22, D23, D24: SK6812; LED_SK6812_PLCC4_5.0x5.0mm_P3.2mm
J1: LedIn_side_a; PinHeader_1x03_P2.54mm_Horizontal_SMD
J2, J3, J5, J6: PQ_side_a; PinHeader_1x02_P2.54mm_Horizontal_SMD
J4: Touch_side_a; PinHeader_1x02_P2.54mm_Horizontal_SMD
J7: LedIn_side_b; PinHeader_1x03_P2.54mm_Horizontal_SMD
J8, J9, J11, J12: PQ_side_b; PinHeader_1x02_P2.54mm_Horizontal_SMD
J10: Touch_side_b; PinHeader_1x02_P2.54mm_Horizontal_SMD
J13: Conn_side_a; PinHeader_1x03_P2.54mm_Horizontal_SMD
J14, J15: IC; PinHeader_1x02_P2.54mm_Horizontal_SMD
J16: Hall; PinHeader_1x03_P2.54mm_Horizontal_SMD
J17: Touch; PinHeader_1x02_P2.54mm_Horizontal_SMD
J18: Led; PinHeader_1x03_P2.54mm_Horizontal_SMD
J19: Conn_side_b; PinHeader_1x02_P2.54mm_Horizontal_SMD
Q1, Q2, Q3, Q4, Q5, Q6, Q7, Q8: 2N3906; SOT-23
R1, R2, R3, R4, R5, R6, R7, R8: R330; R_1206_3216Metric
U1, U2, U3, U4, U5, U6, U7, U8, U9, U10, U11, U12, U13, U14, U15, U16, U17, U18, U19, U20, U21, U22, U23, U24: AH49E; SOT-23
UI1: 74HCT138; SO-16_5.3x10.2mm_P1.27mm
UI2: AMS1117-3.3; SOT-223

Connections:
A0: J15.1, UI1.1 (A0)
A1: J15.2, UI1.2 (A1)
A2: J14.1, UI1.3 (A2)
AGND: J4.1, J10.2, J17.2, U1.3 (GND), U2.3 (GND), U3.3 (GND), U4.3 (GND), U5.3 (GND), U6.3 (GND), U7.3 (GND), U8.3 (GND), U9.3 (GND), U10.3 (GND), U11.3 (GND), U12.3 (GND), U13.3 (GND), U14.3 (GND), U15.3 (GND), U16.3 (GND), U17.3 (GND), U18.3 (GND), U19.3 (GND), U20.3 (GND), U21.3 (GND), U22.3 (GND), U23.3 (GND), U24.3 (GND)
E: J14.2, UI1.6 (E3)
GND: C1.2, C2.2, C3.2, C4.2, C5.2, C6.2, C7.2, C8.2, C9.2, C10.2, C11.2, C12.2, C13.2, C14.2, C15.2, C16.2, C17.2, C18.2, C19.2, C20.2, C21.2, C22.2, C23.2, C24.2, CI1.1, CI2.1, CI3.1, CI4.1, CI5.1, D1.1 (VSS), D2.1 (VSS), D3.1 (VSS), D4.1 (VSS), D5.1 (VSS), D6.1 (VSS), D7.1 (VSS), D8.1 (VSS), D9.1 (VSS), D10.1 (VSS), D11.1 (VSS), D12.1 (VSS), D13.1 (VSS), D14.1 (VSS), D15.1 (VSS), D16.1 (VSS), D17.1 (VSS), D18.1 (VSS), D19.1 (VSS), D20.1 (VSS), D21.1 (VSS), D22.1 (VSS), D23.1 (VSS), D24.1 (VSS), J18.3, UI1.4 (~E1), UI1.5 (~E2), UI1.8 (GND), UI2.1 (GND)
GND_side_a: J1.1, J13.1
GND_side_b: J7.3, J19.1
HallOut1: J16.1, U1.2 (OUT), U4.2 (OUT), U7.2 (OUT), U10.2 (OUT), U13.2 (OUT), U16.2 (OUT), U19.2 (OUT), U22.2 (OUT)
HallOut2: J16.2, U2.2 (OUT), U5.2 (OUT), U8.2 (OUT), U11.2 (OUT), U14.2 (OUT), U17.2 (OUT), U20.2 (OUT), U23.2 (OUT)
HallOut3: J16.3, U3.2 (OUT), U6.2 (OUT), U9.2 (OUT), U12.2 (OUT), U15.2 (OUT), U18.2 (OUT), U21.2 (OUT), U24.2 (OUT)
LedIn: D24.2 (DIN), J18.2
LedIn_side_a: J1.2, J13.2
LedOut: D3.4 (DOUT), J7.2
unnamed: D1.2 (DIN), D4.4 (DOUT)
unnamed: D1.4 (DOUT), D2.2 (DIN)
unnamed: D2.4 (DOUT), D3.2 (DIN)
unnamed: D4.2 (DIN), D5.4 (DOUT)
unnamed: D5.2 (DIN), D6.4 (DOUT)
unnamed: D6.2 (DIN), D9.4 (DOUT)
unnamed: D7.4 (DOUT), D8.2 (DIN)
unnamed: D8.4 (DOUT), D9.2 (DIN)
unnamed: D10.2 (DIN), D11.4 (DOUT)
unnamed: D7.2 (DIN), D10.4 (DOUT)
unnamed: D11.2 (DIN), D12.4 (DOUT)
unnamed: D12.2 (DIN), D15.4 (DOUT)
unnamed: D13.2 (DIN), D16.4 (DOUT)
unnamed: D13.4 (DOUT), D14.2 (DIN)
unnamed: D14.4 (DOUT), D15.2 (DIN)
unnamed: D16.2 (DIN), D17.4 (DOUT)
unnamed: D17.2 (DIN), D18.4 (DOUT)
unnamed: D18.2 (DIN), D21.4 (DOUT)
unnamed: D19.2 (DIN), D22.4 (DOUT)
unnamed: D19.4 (DOUT), D20.2 (DIN)
unnamed: D20.4 (DOUT), D21.2 (DIN)
unnamed: D22.2 (DIN), D23.4 (DOUT)
unnamed: D23.2 (DIN), D24.4 (DOUT)
unnamed: Q1.1 (B), R1.2
unnamed: Q2.1 (B), R2.2
unnamed: Q3.1 (B), R3.2
unnamed: Q4.1 (B), R4.2
unnamed: Q5.1 (B), R5.2
unnamed: Q6.1 (B), R6.2
unnamed: Q7.1 (B), R7.2
unnamed: Q8.1 (B), R8.2
P: C1.1, C2.1, C3.1, C4.1, C5.1, C6.1, C7.1, C8.1, C9.1, C10.1, C11.1, C12.1, C13.1, C14.1, C15.1, C16.1, C17.1, C18.1, C19.1, C20.1, C21.1, C22.1, C23.1, C24.1, CI1.2, CI2.2, CI3.2, D1.3 (VDD), D2.3 (VDD), D3.3 (VDD), D4.3 (VDD), D5.3 (VDD), D6.3 (VDD), D7.3 (VDD), D8.3 (VDD), D9.3 (VDD), D10.3 (VDD), D11.3 (VDD), D12.3 (VDD), D13.3 (VDD), D14.3 (VDD), D15.3 (VDD), D16.3 (VDD), D17.3 (VDD), D18.3 (VDD), D19.3 (VDD), D20.3 (VDD), D21.3 (VDD), D22.3 (VDD), D23.3 (VDD), D24.3 (VDD), J18.1, UI1.16 (VCC), UI2.3 (VI)
P3.3: CI4.2, CI5.2, Q1.2 (E), Q2.2 (E), Q3.2 (E), Q4.2 (E), Q5.2 (E), Q6.2 (E), Q7.2 (E), Q8.2 (E), UI2.2 (VO)
PQ1: J2.2, J8.1, Q1.3 (C), U1.1 (VCC), U2.1 (VCC), U3.1 (VCC)
PQ2: J2.1, J8.2, Q2.3 (C), U4.1 (VCC), U5.1 (VCC), U6.1 (VCC)
PQ3: J3.2, J9.1, Q3.3 (C), U7.1 (VCC), U8.1 (VCC), U9.1 (VCC)
PQ4: J3.1, J9.2, Q4.3 (C), U10.1 (VCC), U11.1 (VCC), U12.1 (VCC)
PQ5: J5.2, J11.1, Q5.3 (C), U13.1 (VCC), U14.1 (VCC), U15.1 (VCC)
PQ6: J5.1, J11.2, Q6.3 (C), U16.1 (VCC), U17.1 (VCC), U18.1 (VCC)
PQ7: J6.2, J12.1, Q7.3 (C), U19.1 (VCC), U20.1 (VCC), U21.1 (VCC)
PQ8: J6.1, J12.2, Q8.3 (C), U22.1 (VCC), U23.1 (VCC), U24.1 (VCC)
P_side_a: J1.3, J13.3
P_side_b: J7.1, J19.2
Q1: R1.1, UI1.15 (Y0)
Q2: R2.1, UI1.14 (Y1)
Q3: R3.1, UI1.13 (Y2)
Q4: R4.1, UI1.12 (Y3)
Q5: R5.1, UI1.11 (Y4)
Q6: R6.1, UI1.10 (Y5)
Q7: R7.1, UI1.9 (Y6)
Q8: R8.1, UI1.7 (Y7)

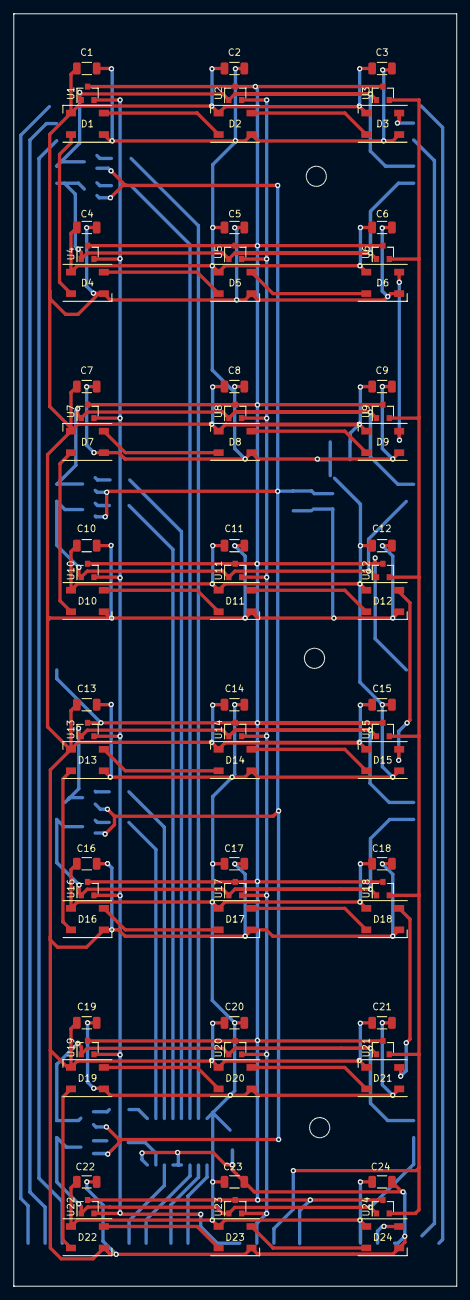
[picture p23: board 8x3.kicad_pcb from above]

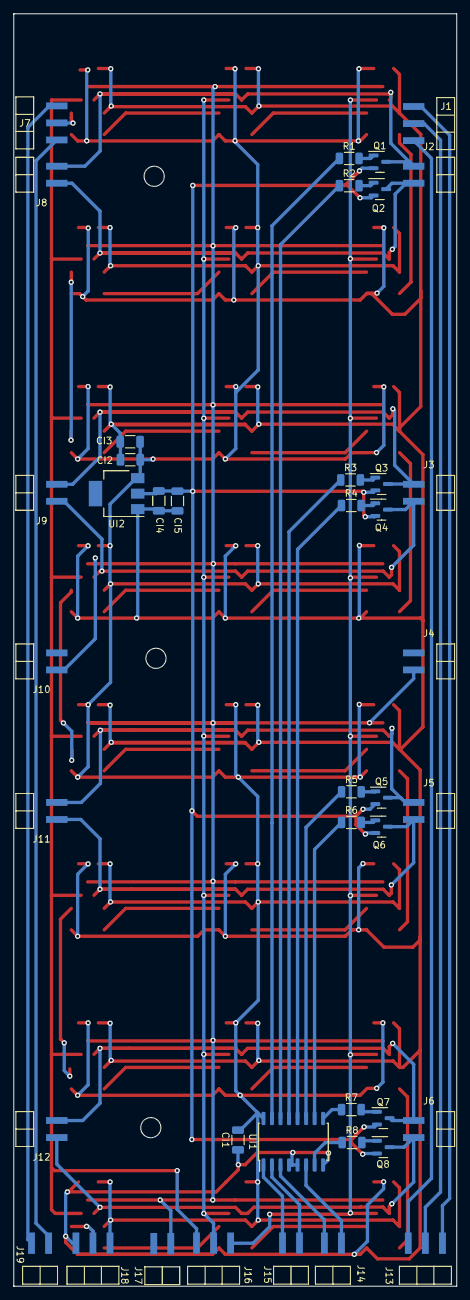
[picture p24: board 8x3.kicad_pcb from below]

Board: 2 copper layers, 66.0 x 189.6 mm, 117 parts (42 on the bottom side), 65 nets.

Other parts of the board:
M1, M2, M3: MountingHole_3mm

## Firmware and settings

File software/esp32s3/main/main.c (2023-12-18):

#include <wifi.h>
#include "esp_log.h"
#include "lwip/sockets.h"
#include <led_strip.h>
#include "esp_adc/adc_oneshot.h"
#include "cJSON.h"
#include "driver/gpio.h"
#include "driver/touch_pad.h"

#define PORT 3333
#define KEEPALIVE_IDLE 5
#define KEEPALIVE_INTERVAL 5
#define KEEPALIVE_COUNT 3
#define EXAMPLE_ADC1_CHAN0 ADC_CHANNEL_0 // Pin 1
#define EXAMPLE_ADC1_CHAN1 ADC_CHANNEL_1 // Pin 2
#define EXAMPLE_ADC1_CHAN2 ADC_CHANNEL_2 // Pin 3
#define EXAMPLE_ADC1_CHAN3 ADC_CHANNEL_3 // Pin 4
#define EXAMPLE_ADC1_CHAN4 ADC_CHANNEL_4 // Pin 5
#define EXAMPLE_ADC1_CHAN5 ADC_CHANNEL_5 // Pin 6
#define EXAMPLE_ADC1_CHAN6 ADC_CHANNEL_6 // Pin 7
#define TOUCH_PIN TOUCH_PAD_NUM8
#define A0_AT_12 GPIO_NUM_41
#define A1_AT_11 GPIO_NUM_40
#define A2_AT_10 GPIO_NUM_39
#define A3_AT_9 GPIO_NUM_38
#define E_AT_6 GPIO_NUM_37
#define S1_AT_2 GPIO_NUM_16
#define S0_AT_3 GPIO_NUM_15
#define LED_PIN_AT_5 GPIO_NUM_17 // PIN 17

static const char *TAG = "TCP/IP socket server";
static adc_oneshot_unit_handle_t adc1_handle;
static led_strip_t strip = {
    .type = LED_STRIP_SK6812,
    .length = 361,
    .gpio = LED_PIN_AT_5,
    .buf = NULL,
    .is_rgbw = true,
};

void _sensor_endpoint(cJSON *answer)
{
    ESP_LOGI(TAG, "Sensors");
    cJSON *hall = cJSON_AddArrayToObject(answer, "hall");
    static uint8_t demux[19][4] = {
        {0, 0, 0, 1}, // 0
        {1, 0, 0, 1}, // 1
        {0, 1, 0, 1}, // 2
        {0, 0, 0, 0}, // 3
        {1, 0, 0, 0}, // 4
        {0, 1, 0, 0}, // 5
        {1, 1, 0, 0}, // 6
        {0, 0, 1, 0}, // 7
        {1, 0, 1, 0}, // 8
        {0, 1, 1, 0}, // 9
        {1, 1, 1, 0}, // 10
        {1, 1, 1, 0}, // 11
        {0, 1, 1, 0}, // 12
        {1, 0, 1, 0}, // 13
        {0, 0, 1, 0}, // 14
        {1, 1, 0, 0}, // 15
        {0, 1, 0, 0}, // 16
        {1, 0, 0, 0}, // 17
        {0, 0, 0, 0}  // 18
    };
    for (int8_t r = 18; r >= 0; r--)
    {
        cJSON *row = cJSON_CreateArray();
        gpio_set_level(E_AT_6, (r > 10) ? 1 : 0);
        gpio_set_level(A0_AT_12, demux[r][0]);
        gpio_set_level(A1_AT_11, demux[r][1]);
        gpio_set_level(A2_AT_10, demux[r][2]);
        gpio_set_level(A3_AT_9, demux[r][3]);
        gpio_set_level(S0_AT_3, 0);
        gpio_set_level(S1_AT_2, 0);
        vTaskDelay(1 / portTICK_PERIOD_MS);
        int raw[19];
        ESP_ERROR_CHECK(adc_oneshot_read(adc1_handle, EXAMPLE_ADC1_CHAN0, &raw[8]));
        ESP_ERROR_CHECK(adc_oneshot_read(adc1_handle, EXAMPLE_ADC1_CHAN1, &raw[9]));
        ESP_ERROR_CHECK(adc_oneshot_read(adc1_handle, EXAMPLE_ADC1_CHAN2, &raw[10]));
        ESP_ERROR_CHECK(adc_oneshot_read(adc1_handle, EXAMPLE_ADC1_CHAN3, &raw[0]));
        ESP_ERROR_CHECK(adc_oneshot_read(adc1_handle, EXAMPLE_ADC1_CHAN4, &raw[1]));
        ESP_ERROR_CHECK(adc_oneshot_read(adc1_handle, EXAMPLE_ADC1_CHAN5, &raw[11]));
        ESP_ERROR_CHECK(adc_oneshot_read(adc1_handle, EXAMPLE_ADC1_CHAN6, &raw[12]));
        gpio_set_level(S0_AT_3, 1);
        gpio_set_level(S1_AT_2, 0);
        vTaskDelay(1 / portTICK_PERIOD_MS);
        ESP_ERROR_CHECK(adc_oneshot_read(adc1_handle, EXAMPLE_ADC1_CHAN3, &raw[2]));
        ESP_ERROR_CHECK(adc_oneshot_read(adc1_handle, EXAMPLE_ADC1_CHAN4, &raw[3]));
        ESP_ERROR_CHECK(adc_oneshot_read(adc1_handle, EXAMPLE_ADC1_CHAN5, &raw[13]));
        ESP_ERROR_CHECK(adc_oneshot_read(adc1_handle, EXAMPLE_ADC1_CHAN6, &raw[14]));
        gpio_set_level(S0_AT_3, 0);
        gpio_set_level(S1_AT_2, 1);
        vTaskDelay(1 / portTICK_PERIOD_MS);
        ESP_ERROR_CHECK(adc_oneshot_read(adc1_handle, EXAMPLE_ADC1_CHAN3, &raw[4]));
        ESP_ERROR_CHECK(adc_oneshot_read(adc1_handle, EXAMPLE_ADC1_CHAN4, &raw[5]));
        ESP_ERROR_CHECK(adc_oneshot_read(adc1_handle, EXAMPLE_ADC1_CHAN5, &raw[15]));
        ESP_ERROR_CHECK(adc_oneshot_read(adc1_handle, EXAMPLE_ADC1_CHAN6, &raw[16]));
        gpio_set_level(S0_AT_3, 1);
        gpio_set_level(S1_AT_2, 1);
        vTaskDelay(1 / portTICK_PERIOD_MS);
        ESP_ERROR_CHECK(adc_oneshot_read(adc1_handle, EXAMPLE_ADC1_CHAN3, &raw[6]));
        ESP_ERROR_CHECK(adc_oneshot_read(adc1_handle, EXAMPLE_ADC1_CHAN4, &raw[7]));
        ESP_ERROR_CHECK(adc_oneshot_read(adc1_handle, EXAMPLE_ADC1_CHAN5, &raw[17]));
        ESP_ERROR_CHECK(adc_oneshot_read(adc1_handle, EXAMPLE_ADC1_CHAN6, &raw[18]));

        for (uint8_t c = 0; c < 19; c++)
        {
            cJSON *c_raw = cJSON_CreateNumber(raw[c]);
            cJSON_AddItemToArray(row, c_raw);
        }
        cJSON_AddItemToArray(hall, row);
    }
    uint32_t touch_value;
    touch_pad_read_raw_data(TOUCH_PIN, &touch_value);
    cJSON_AddNumberToObject(answer, "touch",touch_value);
}

int _row_col_to_nr(int row, int col)
{
    int nr;
    if (col < 8)
    {
        nr = row * 8 + (7 - col) * (row % 2) + col * !(row % 2);
    }
    else if (col > 10)
    {
        nr = row * 8 + 208 + (19 - col) * (row % 2) + (col - 10) * !(row % 2);
    }
    else
    {
        nr = 151 + (18 - row) * 3 + (11 - col) * (row % 2) + (col - 7) * !(row % 2);
    }
    return nr;
}

void _led_endpoint(cJSON *answer, const cJSON *leds)
{
    ESP_LOGI(TAG, "Leds");
    const cJSON *led = NULL;
    cJSON_ArrayForEach(led, leds)
    {
        cJSON *row = cJSON_GetArrayItem(led, 0);
        cJSON *col = cJSON_GetArrayItem(led, 1);
        cJSON *red = cJSON_GetArrayItem(led, 2);
        cJSON *green = cJSON_GetArrayItem(led, 3);
        cJSON *blue = cJSON_GetArrayItem(led, 4);
        cJSON *white = cJSON_GetArrayItem(led, 5);

        if (cJSON_IsNumber(red) && cJSON_IsNumber(green) && cJSON_IsNumber(blue) && cJSON_IsNumber(white))
        {
            ESP_LOGI(TAG, "pos: (%d,%d) r: %d g: %d b: %d, w: %d", row->valueint, col->valueint, red->valueint, green->valueint, blue->valueint, white->valueint);
            led_strip_set_pixel(&strip, _row_col_to_nr(row->valueint, col->valueint), red->valueint, green->valueint, blue->valueint, white->valueint);
        }
    }
    ESP_ERROR_CHECK(led_strip_flush(&strip));
    cJSON_AddStringToObject(answer, "status", "OK");
}

int _process_message(char *message, size_t size)
{
    cJSON *root = cJSON_Parse(message);
    const cJSON *name = cJSON_GetObjectItemCaseSensitive(root, "name");
    cJSON *answer = cJSON_CreateObject();
    if (cJSON_IsString(name) && (name->valuestring != NULL) && strcmp(name->valuestring, "led") == 0)
    {
        const cJSON *leds = cJSON_GetObjectItemCaseSensitive(root, "leds");
        _led_endpoint(answer, leds);
    }
    else
    {
        _sensor_endpoint(answer);
    }
    memset(message, 0, size);
    char *answer_string = cJSON_PrintUnformatted(answer);
    ESP_LOGI(TAG, "%s", answer_string);
    strncpy(message, answer_string, size);
    free(answer_string);
    cJSON_Delete(answer);
    cJSON_Delete(root);
    return strlen(message) + 1;
}

static void _do_retransmit(const int sock)
{
    int len;
    char rx_buffer[10000]; // should be enough for max json send/recv

    do
    {
        memset(rx_buffer, 0, sizeof(rx_buffer)); // Clear the buffer.
        len = recv(sock, rx_buffer, sizeof(rx_buffer) - 1, 0);
        if (len < 0)
        {
            ESP_LOGE(TAG, "Error occurred during receiving: errno %d", errno);
        }
        else if (len == 0)
        {
            ESP_LOGW(TAG, "Connection closed");
        }
        else
        {
            while (rx_buffer[len - 1] != '}')
            {
                len += recv(sock, rx_buffer + len, sizeof(rx_buffer) - len, 0);
            }
            rx_buffer[len] = 0; // Null-terminate whatever is received and treat it like a string
            ESP_LOGI(TAG, "Received %d bytes: %s", len, rx_buffer);
            len = _process_message(rx_buffer, sizeof(rx_buffer));

            // send() can return less bytes than supplied length.
            // Walk-around for robust implementation.
            int to_write = len;
            while (to_write > 0)
            {
                int written = send(sock, rx_buffer + (len - to_write), to_write, 0);
                if (written < 0)
                {
                    ESP_LOGE(TAG, "Error occurred during sending: errno %d", errno);
                }
                to_write -= written;
            }
        }
    } while (len > 0);
}

static void tcp_server_task(void *pvParameters)
{
    char addr_str[128];
    int addr_family = (int)pvParameters;
    int ip_protocol = 0;
    int keepAlive = 1;
    int keepIdle = KEEPALIVE_IDLE;
    int keepInterval = KEEPALIVE_INTERVAL;
    int keepCount = KEEPALIVE_COUNT;
    struct sockaddr_storage dest_addr;

    if (addr_family == AF_INET)
    {
        struct sockaddr_in *dest_addr_ip4 = (struct sockaddr_in *)&dest_addr;
        dest_addr_ip4->sin_addr.s_addr = htonl(INADDR_ANY);
        dest_addr_ip4->sin_family = AF_INET;
        dest_addr_ip4->sin_port = htons(PORT);
        ip_protocol = IPPROTO_IP;
    }

    int listen_sock = socket(addr_family, SOCK_STREAM, ip_protocol);
    if (listen_sock < 0)
    {
        ESP_LOGE(TAG, "Unable to create socket: errno %d", errno);
        vTaskDelete(NULL);
        return;
    }
    int opt = 1;
    setsockopt(listen_sock, SOL_SOCKET, SO_REUSEADDR, &opt, sizeof(opt));

    ESP_LOGI(TAG, "Socket created");

    int err = bind(listen_sock, (struct sockaddr *)&dest_addr, sizeof(dest_addr));
    if (err != 0)
    {
        ESP_LOGE(TAG, "Socket unable to bind: errno %d", errno);
        ESP_LOGE(TAG, "IPPROTO: %d", addr_family);
        goto CLEAN_UP;
    }
    ESP_LOGI(TAG, "Socket bound, port %d", PORT);

    err = listen(listen_sock, 1);
    if (err != 0)
    {
        ESP_LOGE(TAG, "Error occurred during listen: errno %d", errno);
        goto CLEAN_UP;
    }

    while (1)
    {

        ESP_LOGI(TAG, "Socket listening");

        struct sockaddr_storage source_addr;
        socklen_t addr_len = sizeof(source_addr);
        int sock = accept(listen_sock, (struct sockaddr *)&source_addr, &addr_len);
        if (sock < 0)
        {
            ESP_LOGE(TAG, "Unable to accept connection: errno %d", errno);
            break;
        }

        // Set tcp keepalive option
        setsockopt(sock, SOL_SOCKET, SO_KEEPALIVE, &keepAlive, sizeof(int));
        setsockopt(sock, IPPROTO_TCP, TCP_KEEPIDLE, &keepIdle, sizeof(int));
        setsockopt(sock, IPPROTO_TCP, TCP_KEEPINTVL, &keepInterval, sizeof(int));
        setsockopt(sock, IPPROTO_TCP, TCP_KEEPCNT, &keepCount, sizeof(int));
        // Convert ip address to string
        if (source_addr.ss_family == PF_INET)
        {
            inet_ntoa_r(((struct sockaddr_in *)&source_addr)->sin_addr, addr_str, sizeof(addr_str) - 1);
        }
        ESP_LOGI(TAG, "Socket accepted ip address: %s", addr_str);

        _do_retransmit(sock);
        ESP_LOGI(TAG, "Shutdown socket");
        shutdown(sock, 0);
        close(sock);
    }

CLEAN_UP:
    close(listen_sock);
    vTaskDelete(NULL);
}

void init_analog_read(void)
{
    //-------------ADC1 Init---------------//
    adc_oneshot_unit_init_cfg_t init_config1 = {
        .unit_id = ADC_UNIT_1,
    };
    ESP_ERROR_CHECK(adc_oneshot_new_unit(&init_config1, &adc1_handle));
    //-------------ADC1 Config---------------//
    adc_oneshot_chan_cfg_t config = {
        .bitwidth = ADC_BITWIDTH_DEFAULT,
        .atten = ADC_ATTEN_DB_11,
    };
    ESP_ERROR_CHECK(adc_oneshot_config_channel(adc1_handle, EXAMPLE_ADC1_CHAN0, &config));
    ESP_ERROR_CHECK(adc_oneshot_config_channel(adc1_handle, EXAMPLE_ADC1_CHAN1, &config));
    ESP_ERROR_CHECK(adc_oneshot_config_channel(adc1_handle, EXAMPLE_ADC1_CHAN2, &config));
    ESP_ERROR_CHECK(adc_oneshot_config_channel(adc1_handle, EXAMPLE_ADC1_CHAN3, &config));
    ESP_ERROR_CHECK(adc_oneshot_config_channel(adc1_handle, EXAMPLE_ADC1_CHAN4, &config));
    ESP_ERROR_CHECK(adc_oneshot_config_channel(adc1_handle, EXAMPLE_ADC1_CHAN5, &config));
    ESP_ERROR_CHECK(adc_oneshot_config_channel(adc1_handle, EXAMPLE_ADC1_CHAN6, &config));
}

void init_touch_sensor(void)
{
    touch_pad_init();
    touch_pad_config(TOUCH_PIN);
    //touch_pad_set_voltage(TOUCH_HVOLT_MAX,  TOUCH_LVOLT_MAX, TOUCH_HVOLT_ATTEN_MAX);
    touch_pad_denoise_t denoise = {
        /* The bits to be cancelled are determined according to the noise level. */
        .grade = TOUCH_PAD_DENOISE_BIT4,
        .cap_level = TOUCH_PAD_DENOISE_CAP_L4,
    };
    touch_pad_denoise_set_config(&denoise);
    touch_pad_denoise_enable();
    /* Enable touch sensor clock. Work mode is "timer trigger". */
    touch_pad_set_fsm_mode(TOUCH_FSM_MODE_TIMER);
    touch_pad_fsm_start();
}

void init_all(void)
{
    led_start(&strip);
    init_analog_read();
    init_touch_sensor();
    wifi_connect();
    gpio_reset_pin(A0_AT_12);
    gpio_set_direction(A0_AT_12, GPIO_MODE_OUTPUT);
    gpio_reset_pin(A1_AT_11);
    gpio_set_direction(A1_AT_11, GPIO_MODE_OUTPUT);
    gpio_reset_pin(A2_AT_10);
    gpio_set_direction(A2_AT_10, GPIO_MODE_OUTPUT);
    gpio_reset_pin(A3_AT_9);
    gpio_set_direction(A3_AT_9, GPIO_MODE_OUTPUT);
    gpio_reset_pin(E_AT_6);
    gpio_set_direction(E_AT_6, GPIO_MODE_OUTPUT);
    gpio_reset_pin(S1_AT_2);
    gpio_set_direction(S1_AT_2, GPIO_MODE_OUTPUT);
    gpio_reset_pin(S0_AT_3);
    gpio_set_direction(S0_AT_3, GPIO_MODE_OUTPUT);
}

void app_main(void)
{
    init_all();
    xTaskCreate(tcp_server_task, "tcp_server", 32768, (void *)AF_INET, 5, NULL);
}

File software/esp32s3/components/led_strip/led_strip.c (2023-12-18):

/*
 * The MIT License (MIT)
 *
 * Copyright (c) 2020 Ruslan V. Uss <unclerus@gmail.com>
 *
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
 * THE SOFTWARE IS PROVIDED "AS IS", WITHOUT WARRANTY OF ANY KIND, EXPRESS OR
 * IMPLIED, INCLUDING BUT NOT LIMITED TO THE WARRANTIES OF MERCHANTABILITY,
 * FITNESS FOR A PARTICULAR PURPOSE AND NONINFRINGEMENT. IN NO EVENT SHALL THE
 * AUTHORS OR COPYRIGHT HOLDERS BE LIABLE FOR ANY CLAIM, DAMAGES OR OTHER
 * LIABILITY, WHETHER IN AN ACTION OF CONTRACT, TORT OR OTHERWISE, ARISING FROM,
 * OUT OF OR IN CONNECTION WITH THE SOFTWARE OR THE USE OR OTHER DEALINGS IN THE
 * SOFTWARE.
 */

/**
 * @file led_strip.c
 *
 * RMT-based ESP-IDF driver for WS2812B/SK6812/APA106/SM16703 LED strips
 *
 * Copyright (c) 2020 Ruslan V. Uss <unclerus@gmail.com>
 *
 * MIT Licensed as described in the file LICENSE
 */
#include "led_strip.h"
#include <esp_log.h>
#include <esp_attr.h>
#include <stdlib.h>
#include <esp32s3/rom/ets_sys.h>

#ifndef RMT_DEFAULT_CONFIG_TX
#define RMT_DEFAULT_CONFIG_TX(gpio, channel_id)      \
    {                                                \
        .rmt_mode = RMT_MODE_TX,                     \
        .channel = channel_id,                       \
        .gpio_num = gpio,                            \
        .clk_div = 80,                               \
        .mem_block_num = 1,                          \
        .tx_config = {                               \
            .carrier_freq_hz = 38000,                \
            .carrier_level = RMT_CARRIER_LEVEL_HIGH, \
            .idle_level = RMT_IDLE_LEVEL_LOW,        \
            .carrier_duty_percent = 33,              \
            .carrier_en = false,                     \
            .loop_en = false,                        \
            .idle_output_en = true,                  \
        }                                            \
    }
#endif

static const char *TAG = "led_strip";

#define LED_STRIP_RMT_CLK_DIV 2

#define CHECK(x) do { esp_err_t __; if ((__ = x) != ESP_OK) return __; } while (0)
#define CHECK_ARG(VAL) do { if (!(VAL)) return ESP_ERR_INVALID_ARG; } while (0)

#define COLOR_SIZE(strip) (3 + ((strip)->is_rgbw != 0))

#define LED_STRIP_FLUSH_TIMEOUT 1000
#define LED_STRIP_PAUSE_LENGTH 50

static void IRAM_ATTR _rmt_adapter(const void *src, rmt_item32_t *dest, size_t src_size,
                                   size_t wanted_num, size_t *translated_size, size_t *item_num,
                                   const rmt_item32_t *bit0, const rmt_item32_t *bit1)
{
    if (!src || !dest)
    {
        *translated_size = 0;
        *item_num = 0;
        return;
    }
    size_t size = 0;
    size_t num = 0;
    uint8_t *psrc = (uint8_t *)src;
    rmt_item32_t *pdest = dest;
    while (size < src_size && num < wanted_num)
    {
        uint8_t b = *psrc;
        for (int i = 0; i < 8; i++)
        {
            // MSB first
            pdest->val = b & (1 << (7 - i)) ? bit1->val : bit0->val;
            num++;
            pdest++;
        }
        size++;
        psrc++;
    }
    *translated_size = size;
    *item_num = num;
}

typedef struct {
    rmt_item32_t bit0, bit1;
} led_rmt_t;

static led_rmt_t rmt_items[LED_STRIP_TYPE_MAX] = { 0 };

static void IRAM_ATTR ws2812_rmt_adapter(const void *src, rmt_item32_t *dest, size_t src_size,
        size_t wanted_num, size_t *translated_size, size_t *item_num)
{
    _rmt_adapter(src, dest, src_size, wanted_num, translated_size, item_num, &rmt_items[LED_STRIP_WS2812].bit0, &rmt_items[LED_STRIP_WS2812].bit1);
}

static void IRAM_ATTR sk6812_rmt_adapter(const void *src, rmt_item32_t *dest, size_t src_size,
        size_t wanted_num, size_t *translated_size, size_t *item_num)
{
    _rmt_adapter(src, dest, src_size, wanted_num, translated_size, item_num, &rmt_items[LED_STRIP_SK6812].bit0, &rmt_items[LED_STRIP_SK6812].bit1);
}

static void IRAM_ATTR apa106_rmt_adapter(const void *src, rmt_item32_t *dest, size_t src_size,
        size_t wanted_num, size_t *translated_size, size_t *item_num)
{
    _rmt_adapter(src, dest, src_size, wanted_num, translated_size, item_num, &rmt_items[LED_STRIP_APA106].bit0, &rmt_items[LED_STRIP_APA106].bit1);
}

static void IRAM_ATTR sm16703_rmt_adapter(const void *src, rmt_item32_t *dest, size_t src_size,
                                         size_t wanted_num, size_t *translated_size, size_t *item_num)
{
    _rmt_adapter(src, dest, src_size, wanted_num, translated_size, item_num, &rmt_items[LED_STRIP_SM16703].bit0, &rmt_items[LED_STRIP_SM16703].bit1);
}

typedef enum {
    ORDER_GRB,
    ORDER_RGB,
} color_order_t;

typedef struct {
    uint32_t t0h, t0l, t1h, t1l;
    color_order_t order;
    sample_to_rmt_t adapter;
} led_params_t;

static const led_params_t led_params[] = {
    [LED_STRIP_WS2812]  = { .t0h = 400, .t0l = 1000, .t1h = 1000, .t1l = 400, .order = ORDER_GRB, .adapter = ws2812_rmt_adapter },
    [LED_STRIP_SK6812]  = { .t0h = 300, .t0l = 900,  .t1h = 600,  .t1l = 600, .order = ORDER_GRB, .adapter = sk6812_rmt_adapter },
    [LED_STRIP_APA106]  = { .t0h = 350, .t0l = 1360, .t1h = 1360, .t1l = 350, .order = ORDER_RGB, .adapter = apa106_rmt_adapter },
    [LED_STRIP_SM16703] = { .t0h = 300, .t0l = 900,  .t1h = 1360, .t1l = 350, .order = ORDER_RGB, .adapter = sm16703_rmt_adapter },
};

///////////////////////////////////////////////////////////////////////////////

void led_strip_install()
{
    float ratio = (float)APB_CLK_FREQ / LED_STRIP_RMT_CLK_DIV / 1e09f;

    for (size_t i = 0; i < LED_STRIP_TYPE_MAX; i++)
    {
        // 0 bit
        rmt_items[i].bit0.duration0 = (uint32_t)(ratio * led_params[i].t0h);
        rmt_items[i].bit0.level0 = 1;
        rmt_items[i].bit0.duration1 = (uint32_t)(ratio * led_params[i].t0l);
        rmt_items[i].bit0.level1 = 0;
        // 1 bit
        rmt_items[i].bit1.duration0 = (uint32_t)(ratio * led_params[i].t1h);
        rmt_items[i].bit1.level0 = 1;
        rmt_items[i].bit1.duration1 = (uint32_t)(ratio * led_params[i].t1l);
        rmt_items[i].bit1.level1 = 0;
    }
}

esp_err_t led_strip_init(led_strip_t *strip)
{
    CHECK_ARG(strip && strip->length > 0 && strip->type < LED_STRIP_TYPE_MAX);

    strip->buf = calloc(strip->length, COLOR_SIZE(strip));
    if (!strip->buf)
    {
        ESP_LOGE(TAG, "Not enough memory");
        return ESP_ERR_NO_MEM;
    }

    rmt_config_t config = RMT_DEFAULT_CONFIG_TX(strip->gpio, strip->channel);
    config.clk_div = LED_STRIP_RMT_CLK_DIV;

    CHECK(rmt_config(&config));
    CHECK(rmt_driver_install(config.channel, 0, 0));

    CHECK(rmt_translator_init(config.channel, led_params[strip->type].adapter));

    return ESP_OK;
}

void led_start(led_strip_t *strip)
{
    led_strip_install();
    ESP_ERROR_CHECK(led_strip_init(strip));
}
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
